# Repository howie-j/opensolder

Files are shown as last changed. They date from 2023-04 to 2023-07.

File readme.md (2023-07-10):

# OpenSolder
Fully open source JBC T245-compatible soldering station and tool holder  
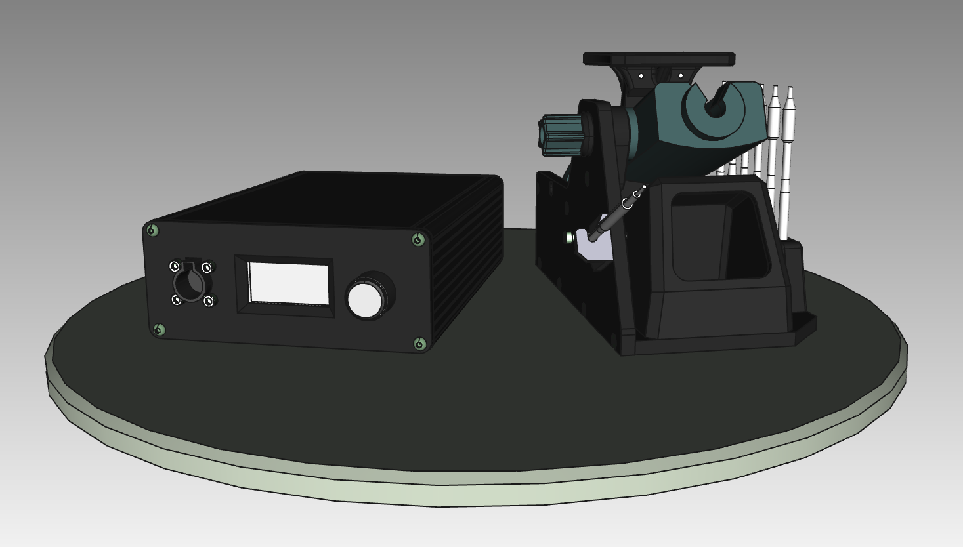
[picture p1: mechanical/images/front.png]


## Introduction
When my cheap T12 clone soldering station went up in smoke, I started looking into either buying a JBC CDB, or building a proper soldering station. The internet is already crowded with DIY JBC compatible stations, but most are poorly documented, or does not have the quality-of-life features that the original have.

The [unisolder project](https://github.com/sparkybg/UniSolder-5.2) is very impressive, but way to complex and "universal" for my needs. [Marco Reps](https://youtu.be/GYIiOkr6x9o) built a cool C470 station that i liked the simplicity of, and this project is highly inspired by that.

## Goals:
- _T12 clone_ form factor that does not take up valuable bench space
- JBC T245 tip compatibility, with similar performance to the original station
- QoL features that the CDB station have, like auto standby, tip remover, holder, tip cleaner etc.
- Simple design using cheap off-the-shelf parts
- A compact handpiece stand with these features:
	- Detection when the handpiece is in the tool holder (auto standby)
	- Detection when you're about to swap tips (cut power)
	- Integrated tip remover, tip storage, tip cleaner and a soldering wire spool holder
	- Simple to build

## Design Specifications
- 24V toroidal transformer
- Zero Crossing AC switching
- OLED display and rotary encoder for adjusting temperature
- Compact and low profile design
- Super fast heatup time (~4s)
- Hardware should be mostly 3D printable, and easy to build using regular tools

## Station
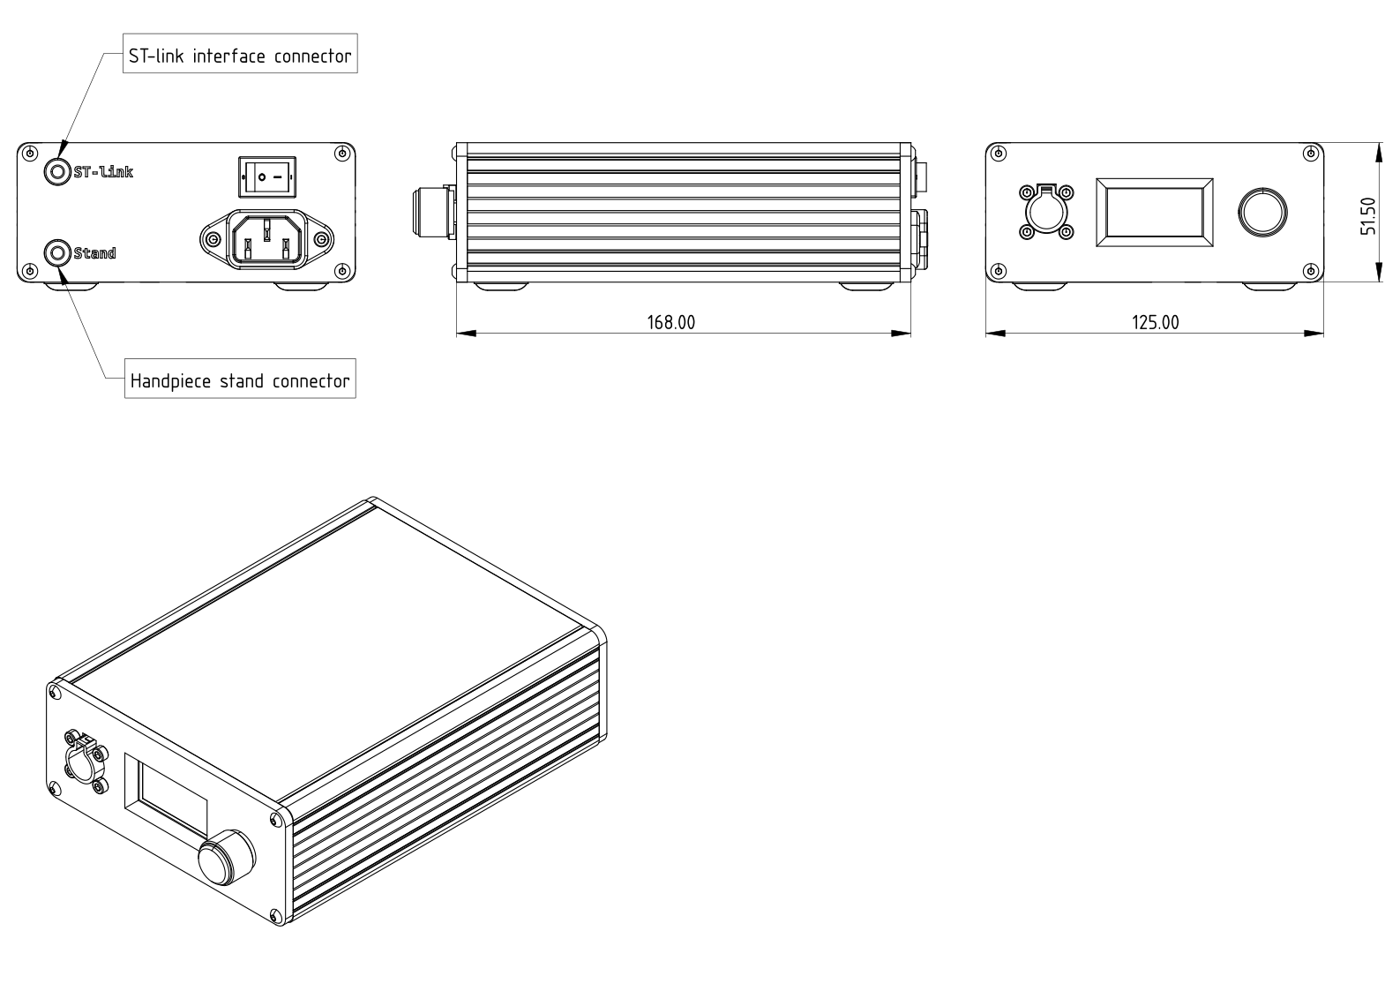
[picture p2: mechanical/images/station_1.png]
  
The station is built in a Hammond enclosure, with a center mounted transformer. The PCB is mounted to the custom front panel, and all 230VAC connections is in the rear of the chassis.
There is two connectors on the rear panel, one for connecting to the stand, and an optional ST-link connector for firmware upgrades.

## Stand
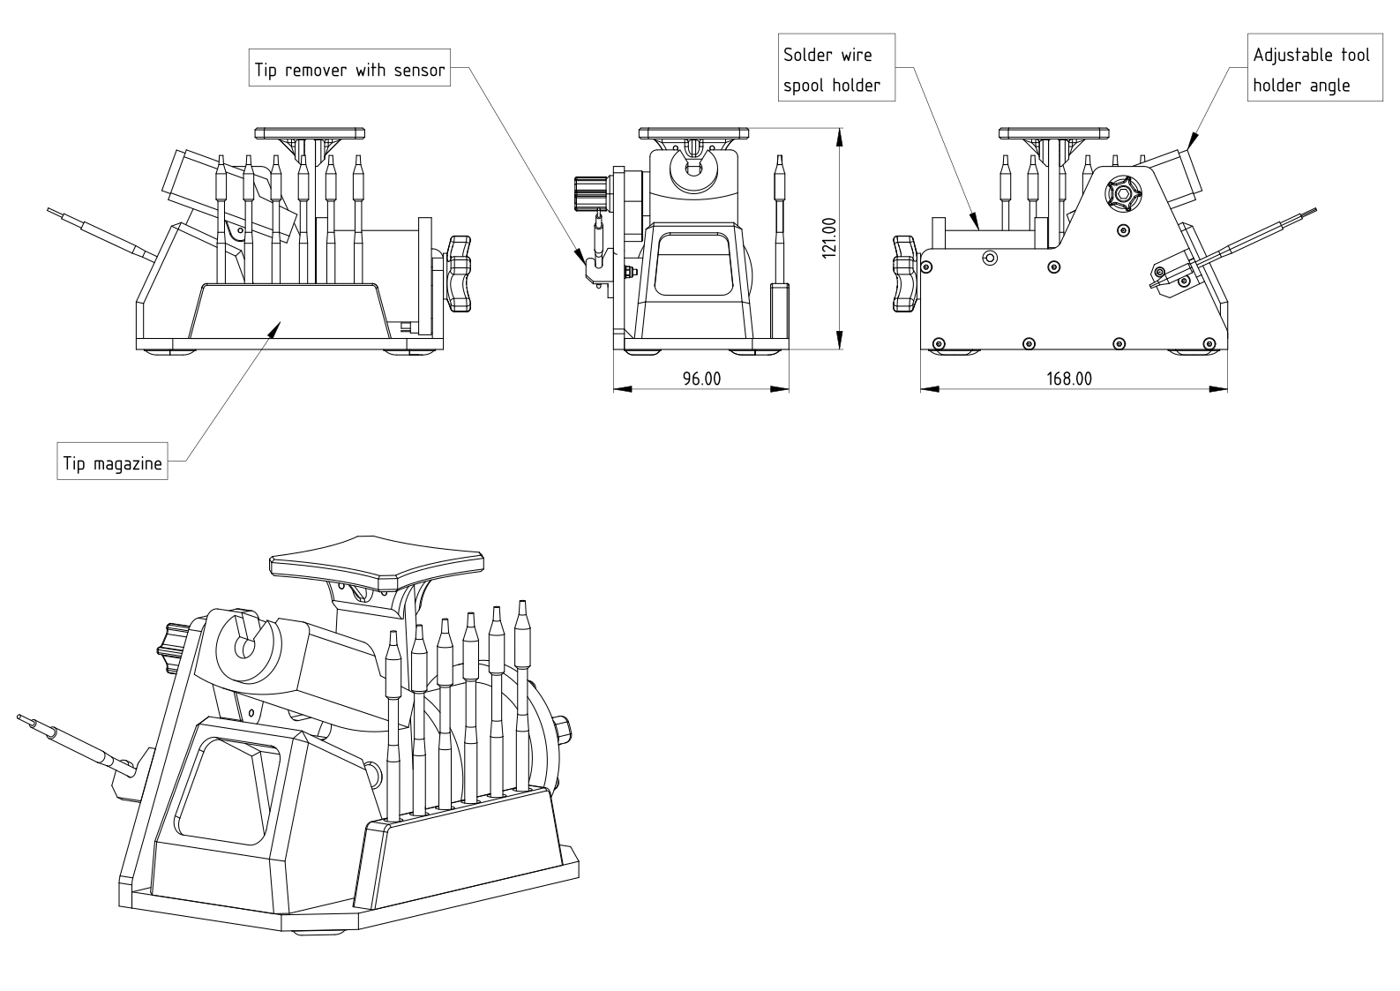
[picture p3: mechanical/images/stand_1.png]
  
The stand is made of 3D-printed parts, a genuine JBC tool holder, a tip remover made from aluminium angle and some fasteners. Most parts can be made from aluminium sheet if that is preferred.

## Schematic
This is the internal connections of the JBC C245 cartridge:  
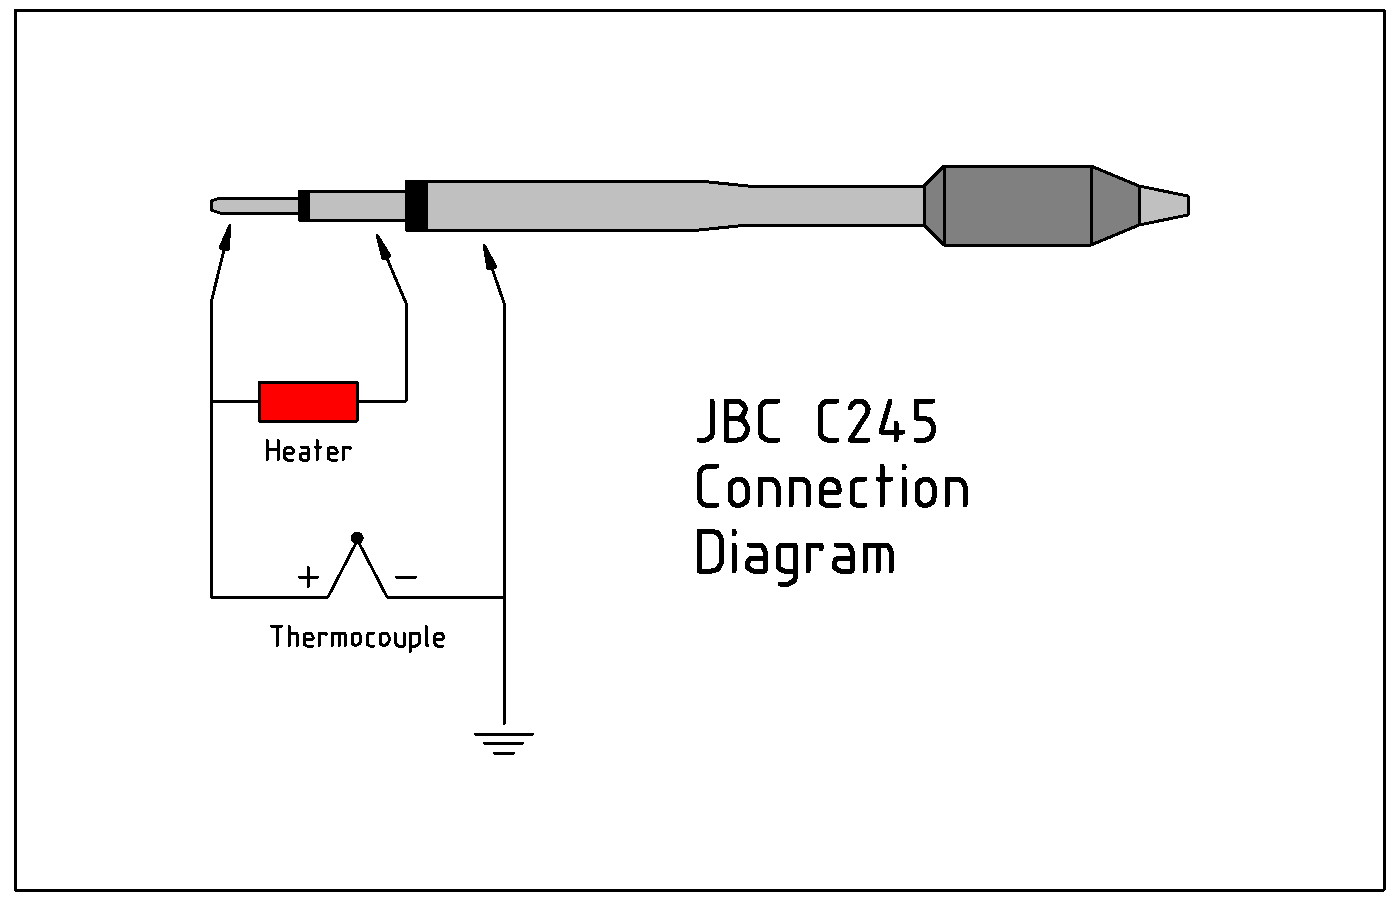
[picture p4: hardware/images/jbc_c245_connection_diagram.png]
  

[__The schematic__](https://github.com/howie-j/OpenSolder/raw/main/hardware/schematic.pdf) is divided into three sheets: AC, Analog and MCU.

### AC
The 24VAC input is fused, then connected directly to the tip center pin (5). Switching is done with two N-channel mosfets, driven by a Si8751 isolated gate driver.

Zero cross detection is done with an AC optocoupler, and the current is limited by three 10k resistors (to reduce BOM items). This solution triggers the ZeroCross about 90uS prematurely, and that is compensated for in firmware.

The MCU and thermocouple frontend must be electrically isolated, and a 24V to 5V DCDC PSU module solves that problem. The DCDC-supply is preregulated with a 24V linear regulator, and post-regulated to 3.3V with a LDO. This power supply chain is in need of some simplification, but the components are few and cheap, and it works great for now.

### Analog
The thermocouple signal is amplified with a MAX4238 chopper opamp, with a fairly arbitrary amplification of 221, since temperature calibration is done in firmware anyway. No negative supply rail means the thermocouple can't sense lower temperatures than room temp, but that's not needed for a soldering station.

Long handpiece wires means lots of crosstalk, so a pair of diodes clamps the thermocouple input at Vf. The MCU pin _TIP_CLAMP_ is driven low when power is applied to the handpiece, to clamp noise on the opamp input. When its time to measure tip temperature, the pin is set to input, and a delay waits for the RC filter to stabilize.

To sense if there is a tip cartridge in the handpiece, _TIP_CHECK_ is driven high. The low impedance of the thermocouple + heater (a few Ω's) will create a very low voltage drop. If the tip is removed, the Vf of the input protection diode will drive _THERMOCOUPLE_ADC_ close to 3.3V.

### MCU
A STM32F072 is used since I have a few of them in stock, but almost any STM32 could be adapted to work. To sense PCB temperature (and for cold junction compensation), an I2C temp sensor is added. The MCU might have an internal temperature sensor, but  have not looked into that yet.

The rotary encoder and handpiece stand inputs are filtered using plain RC filters. This, combined with the input hysteresis, removes most input noise. The TIM encoder inputs also have additional filtering and FSM redundancy.

## PCB
[___Check out this interactive BOM___](http://htmlpreview.github.io/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)

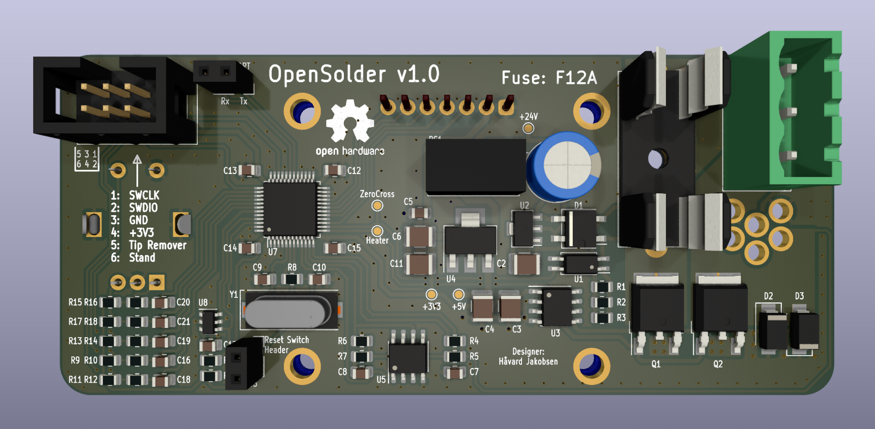
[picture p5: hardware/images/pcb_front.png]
  
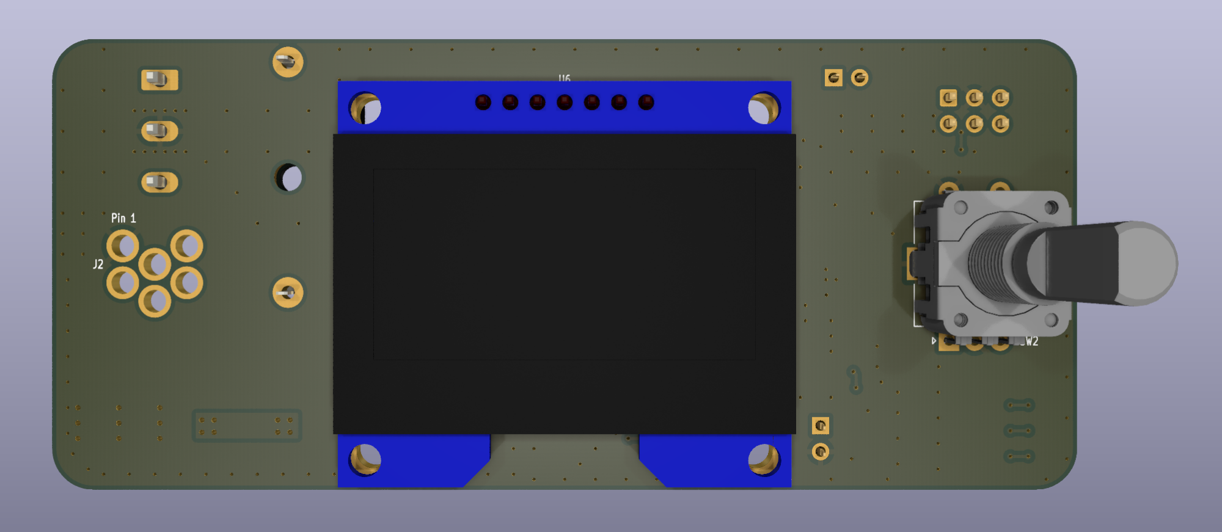
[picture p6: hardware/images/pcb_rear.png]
  
The PCB is quite low density, uses 0805 SMD components and is fully hand solderable with a microscope. Connections to the rear connectors (stand and ST-link) is done via a 6-pin IDC connector, so no crimping of tiny connector pins are necessary. The PCB is mounted to the front panel via the rotary encoder and the handpiece connector.

## Firmware
The firmware is simple and functional, and uses a modified hysteresis temperature controller that is very fast but has some initial overshoot. Currently all default values are set in _opensolder.h_, and are reset when the station is powered off.

### TODO
Nothing is currently missing for regular functionality. However some features would be cool to have:

- More accurate temp control (PID or other controller)
- User changeable default values
- Menu for changing default values
- Better looking UI

## Links and Sources
[The unisolder project](https://github.com/sparkybg/UniSolder-5.2)  
[Marco Reps](https://youtu.be/GYIiOkr6x9o)  
[foldvarid93's JBC Soldering Station](https://github.com/foldvarid93/JBC_SolderingStation)  
[johnmx's eevblog thread](https://eevblog.com/forum/testgear/jbc-soldering-station-cd-2bc-complete-schematic-analysis/)

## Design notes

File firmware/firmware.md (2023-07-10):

### Installation
Install STM32CubeIDE, click "Open project from filesystem" and select the "opensolder" folder.

### Code structure
All cube-generated files are untouched, except for calling opensolder_init() and opensolder_main() in main.c.
- opensolder.c is the "main" file, containing the init calls, superloop and state machine
- opensolder.h contains most constants for easy editing
- temperature.c handles interrupts, does temperature control, adc reading, tip check and such
- gui.c contains all functions to draw graphics to the OLED display

There is a fair bit of comments in the code, and better documentation can be provided if requested. If you have a question or see an issue, just open an issue in this repo.

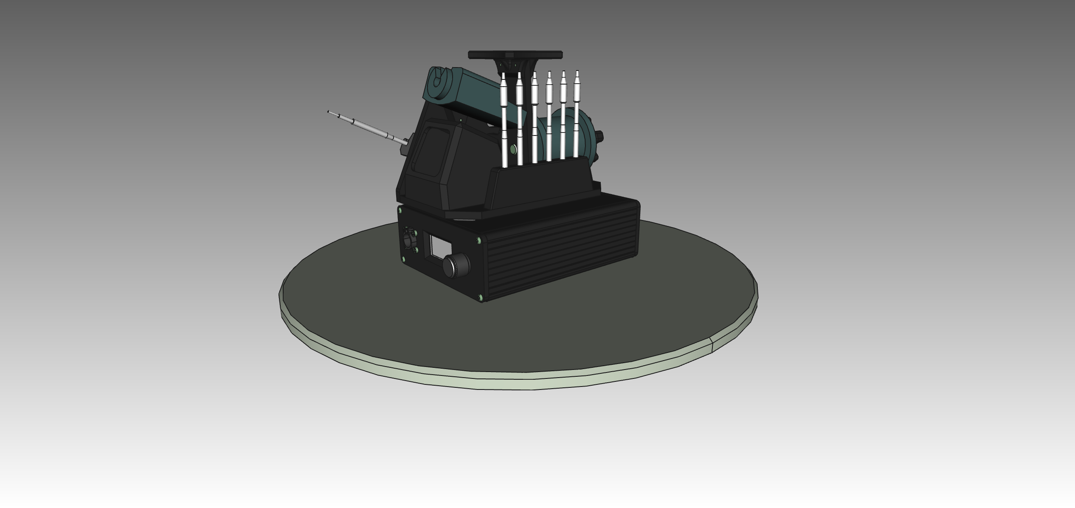
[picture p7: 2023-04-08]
mechanical/images/top_1.png

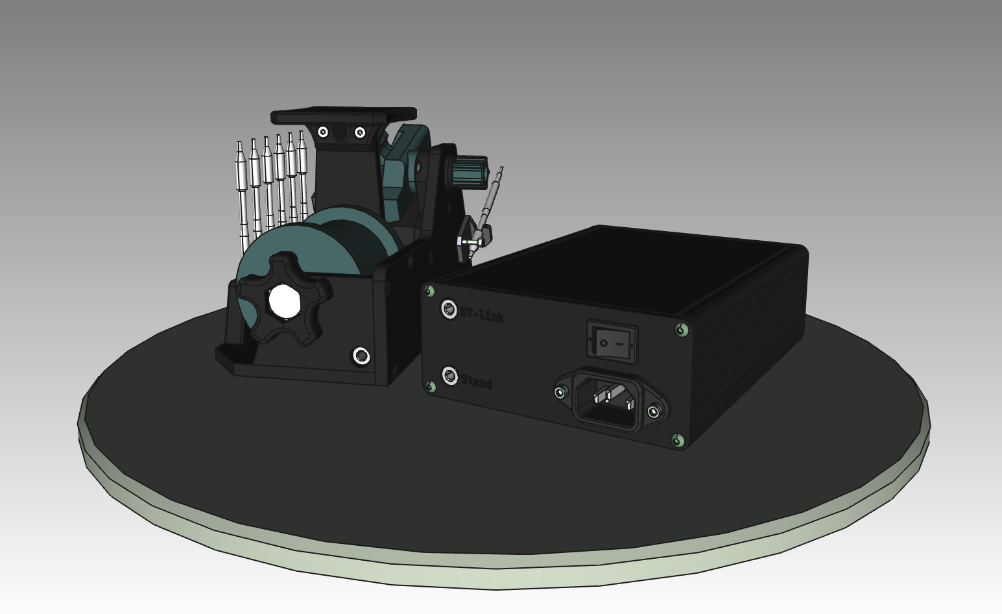
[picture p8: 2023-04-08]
mechanical/images/rear.png

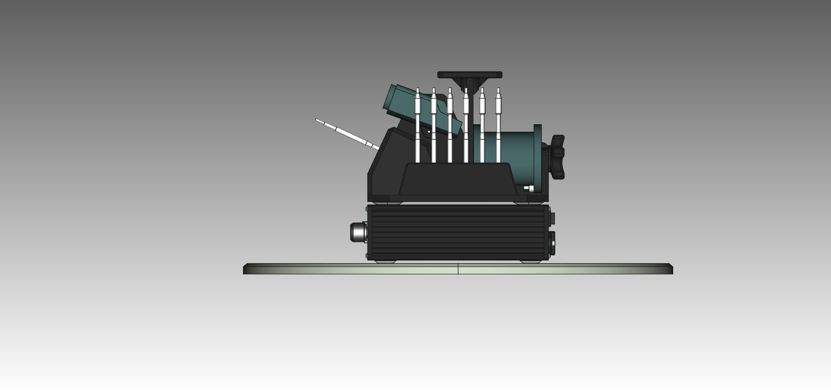
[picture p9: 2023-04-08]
mechanical/images/top_6_ortho.png

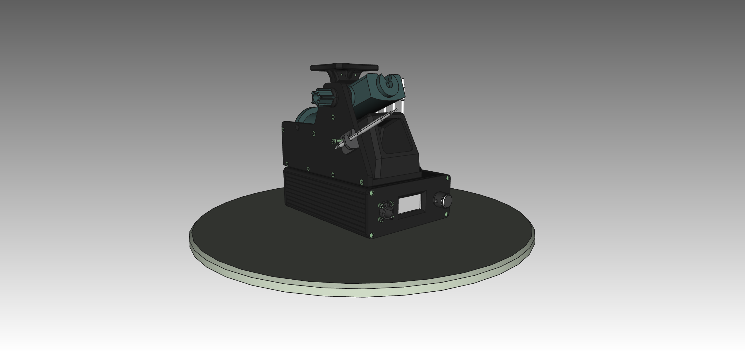
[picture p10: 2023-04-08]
mechanical/images/top_2.png

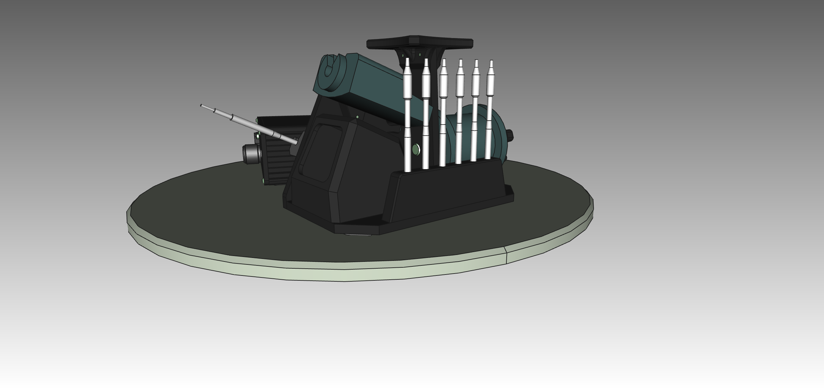
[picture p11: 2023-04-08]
mechanical/images/side_2.png

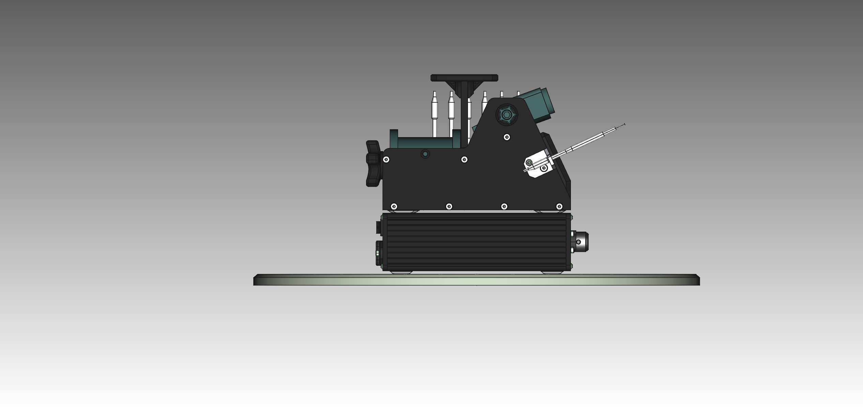
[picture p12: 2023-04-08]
mechanical/images/top_4_ortho.png

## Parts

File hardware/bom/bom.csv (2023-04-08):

Item | Qty | Reference(s) | Value | LibPart | Footprint | Datasheet
1 | 1 | C1 | 47u | Device:C_Polarized_Small | Capacitor_THT:CP_Radial_D8.0mm_P3.50mm | ~
2 | 5 | C2, C3, C4, C6, C11 | 1u | Device:C_Small | Capacitor_SMD:C_1210_3225Metric | ~
3 | 10 | C5, C8, C12, C13, C14, C15, C16, C17, C18, C19 | 100n | Device:C_Small | Capacitor_SMD:C_0805_2012Metric | ~
4 | 3 | C7, C20, C21 | 10n | Device:C_Small | Capacitor_SMD:C_0805_2012Metric | ~
5 | 2 | C9, C10 | 20p | Device:C_Small | Capacitor_SMD:C_0805_2012Metric | ~
6 | 1 | D1 | MB6S-TP | 0_Howie:MB6S-TP | Package_TO_SOT_SMD:TO-269AA
7 | 2 | D2, D3 | S1M | 0_Howie:S1M | Diode_SMD:D_SMA
8 | 1 | F1 | Fast 12A | Device:Fuse | Fuse:Fuseholder_Cylinder-5x20mm_Schurter_0031_8201_Horizontal_Open | ~
9 | 1 | J1 | AC_Input | Connector_Generic:Conn_01x03 | Connector_Phoenix_MSTB:PhoenixContact_MSTBVA_2,5_3-G_1x03_P5.00mm_Vertical | ~
10 | 1 | J2 | Hirose RPC1-12RB-6P(71) | 0_Howie:Hirose RPC1-12RB-6P(71) | 0_Howie:Hirose_RPC1
11 | 1 | J3 | SWD | Connector_Generic:Conn_01x06 | Connector_IDC:IDC-Header_2x03_P2.54mm_Vertical | ~
12 | 1 | J4 | UART | Connector_Generic:Conn_01x02 | Connector_PinSocket_2.54mm:PinSocket_1x02_P2.54mm_Vertical | ~
13 | 1 | J5 | Reset_Switch | Connector_Generic:Conn_01x02 | Connector_PinSocket_2.54mm:PinSocket_1x02_P2.54mm_Vertical | ~
14 | 1 | PS1 | PDSE1-S24-S5-S | 0_Howie:PDSE1-S24-S5-S | 0_Howie:PDSE1_DCDC
15 | 2 | Q1, Q2 | KIA50N06BD | 0_Howie:KIA50N06BD | Package_TO_SOT_SMD:TO-252-2
16 | 10 | R1, R2, R3, R4, R5, R9, R11, R13, R15, R17 | 10k | Device:R_Small | Resistor_SMD:R_0805_2012Metric | ~
17 | 1 | R6 | 22k | Device:R_Small | Resistor_SMD:R_0805_2012Metric | ~
18 | 1 | R7 | 100 | Device:R_Small | Resistor_SMD:R_0805_2012Metric | ~
19 | 1 | R8 | 390 | Device:R_Small | Resistor_SMD:R_0805_2012Metric | ~
20 | 5 | R10, R12, R14, R16, R18 | 100k | Device:R_Small | Resistor_SMD:R_0805_2012Metric | ~
21 | 2 | R19, R20 | 3k3 | Device:R_Small | Resistor_SMD:R_0805_2012Metric | ~
22 | 1 | SW2 | PEC11R-4220F-S0024 | 0_Howie:PEC11R-RotEnc | 0_Howie:RotaryEncoder_PEC11R_PEC12R | ~
23 | 1 | TP1 | ZeroCross | 0_Howie:TestPoint_D1_Pad | TestPoint:TestPoint_Pad_D1.0mm | ~
24 | 1 | TP2 | +24V | 0_Howie:TestPoint_D1_Pad | TestPoint:TestPoint_Pad_D1.0mm | ~
25 | 1 | TP3 | Heater | 0_Howie:TestPoint_D1_Pad | TestPoint:TestPoint_Pad_D1.0mm | ~
26 | 1 | TP4 | +5V | 0_Howie:TestPoint_D1_Pad | TestPoint:TestPoint_Pad_D1.0mm | ~
27 | 1 | TP5 | +3V3 | 0_Howie:TestPoint_D1_Pad | TestPoint:TestPoint_Pad_D1.0mm | ~
28 | 1 | U1 | VOS628A | 0_Howie:VOS628A | Package_SO:SOP-4_4.4x2.6mm_P1.27mm
29 | 1 | U2 | L78L24_SOT89 | Regulator_Linear:L78L24_SOT89 | Package_TO_SOT_SMD:SOT-89-3 | http://www.st.com/content/ccc/resource/technical/document/datasheet/15/55/e5/aa/23/5b/43/fd/CD00000446.pdf/files/CD00000446.pdf/jcr:content/translations/en.CD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
30 | 1 | U3 | Si8751 | 0_Howie:Si8751 | Package_SO:SOIC-8_3.9x4.9mm_P1.27mm
31 | 1 | U4 | AP2111H-3.3 | 0_Howie:AP2111H-3.3 | Package_TO_SOT_SMD:SOT-223
32 | 1 | U5 | MAX4238ASA | Amplifier_Operational:MAX4238ASA | Package_SO:SOIC-8_3.9x4.9mm_P1.27mm | http://datasheets.maximintegrated.com/en/ds/MAX4238-MAX4239.pdf
33 | 1 | U6 | OLED | 0_Howie:OLED_SSD1306_SPI_1.54 | 0_Howie:OLED_SSD1306_SPI_1.54
34 | 1 | U7 | STM32F072CBTx | MCU_ST_STM32F0:STM32F072CBTx | Package_QFP:LQFP-48_7x7mm_P0.5mm | http://www.st.com/st-web-ui/static/active/en/resource/technical/document/datasheet/DM00090510.pdf
35 | 1 | U8 | PCT2075GV | 0_Howie:PCT2075GV | Package_SO:TSOP-6_1.65x3.05mm_P0.95mm | https://www.nxp.com/docs/en/data-sheet/PCT2075.pdf
36 | 1 | Y1 | Crystal_8MHz | 0_Howie:Crystal_8MHz | Crystal:Crystal_SMD_HC49-SD | ~

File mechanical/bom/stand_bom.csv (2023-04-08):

Position | Component | Part Number / Specification | Manufacturer | Material | Qty | Description
1 | Base Panel | OpenSolder Stand Base Panel | DIY | ABS | 1 | Alternative material: Aluminium sheet
2 | Side Panel | OpenSolder Stand Side Panel | DIY | ABS | 1 | Alternative material: Aluminium sheet
3 | Rear Panel | OpenSolder Stand Rear Panel | DIY | ABS | 1 | Alternative material: Aluminium sheet
4 | Mid Panel | OpenSolder Stand Mid Panel | DIY | ABS | 1 | Alternative material: Aluminium sheet
5 | Handle | OpenSolder Stand Handle | DIY | ABS | 1
6 | Tool Holder SCD | 12994 | JBC | - | 1
7 | Tool Holder Adapter | OpenSolder Tool Holder Adapter | DIY | ABS | 1
8 | Tool Holder Washer | OpenSolder Tool Holder Washer | DIY | ABS | 1
9 | Spool Knob | OpenSolder Spool Knob | DIY | ABS | 1
10 | Tip Magazine | OpenSolder Tip Magazine | DIY | ABS | 1
11 | Tip Cleaner | OpenSolder Tip Cleaner | DIY | ABS | 1
12 | Tip Remover Bracket | OpenSolder Tip Remover Bracket | DIY | Aluminium | 1
13 | Connector | MJ-064H | Marushin Electric | - | 1
14 | Rubber Pads | Self adhesive | - | - | 4
15 | CS Flat Head Screw M3X8 | ISO 10642 | - | - | 3
16 | CS Flat Head Screw M3X16 | ISO 10642 | - | - | 15
17 | Socket Head Cap Screw M3x25 | ISO 4762 | - | - | 1
18 | Washer M3 | ISO 7089 | - | - | 1
19 | Locknut M3 | ISO 10511 | - | - | 1
20 | Hexagon Screw M10x80 | ISO 4014 | - | - | 1

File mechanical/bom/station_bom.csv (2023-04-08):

Position | Component | Part Number / Specification | Manufacturer | Material | Qty | Description
1 | Enclosure | 1455Q1602BK | Hammond | - | 1
2 | PCBA | OpenSolder PCBA | DIY | - | 1
3 | Front Panel | OpenSolder Front Panel | DIY | ABS | 1 | Alternative material: Aluminium sheet
4 | Rear Panel | OpenSolder Front Panel | DIY | ABS | 1 | Alternative material: Aluminium sheet
5 | Transformer Spacer | OpenSolder Transformer Spacer | DIY | ABS | 1
6 | Transformer kit | TI-044229-ME-ES | Noratel | - | 1 | 24VAC, 100VA min, D105xH46 max size
7 | IDC Power Inlet | 703W-00/04 | Qualtek | - | 1
8 | Power Switch | CWSB11AA2F | NKK Switches | - | 1
9 | Fuse holder inline | 01500274ZXU | Littelfuse Inc. | - | 1
10 | Connector | MJ-064H | Marushin Electric | - | 2
11 | Rubber Pads | Self adhesive | - | - | 4
12 | Knob | Ø6, D-shaft, set screw | - | - | 1
13 | Socket Head Cap Screw M3x8 | ISO 4762 | - | - | 4
14 | Socket Head Cap Screw M3x12 | ISO 4762 | - | - | 2
15 | CS Flat Head Screw M3X12 | ISO 10642 | - | - | 1
16 | Washer M3 | ISO 7089 | - | - | 3
17 | Locknut M3 | ISO 10511 | - | - | 3
18 | Button Head Screw M3.5x16 | ISO 7380 | - | - | 8
19 | CS Flat Head Screw M5x20 | ISO 10642 | - | - | 2
20 | Locknut M5 | ISO 10511 | - | - | 2

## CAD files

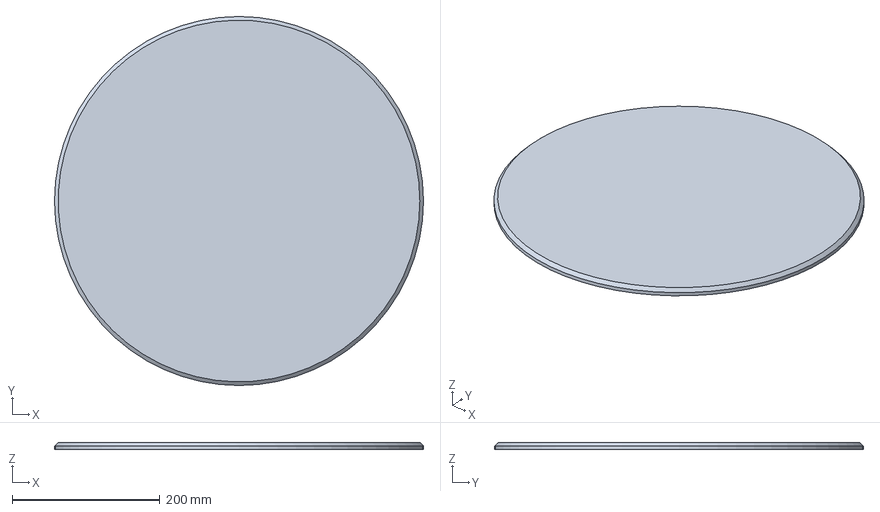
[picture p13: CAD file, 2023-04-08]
mechanical/freecad/Render Assembly.FCStd
500.0 x 500.0 x 10.0 mm

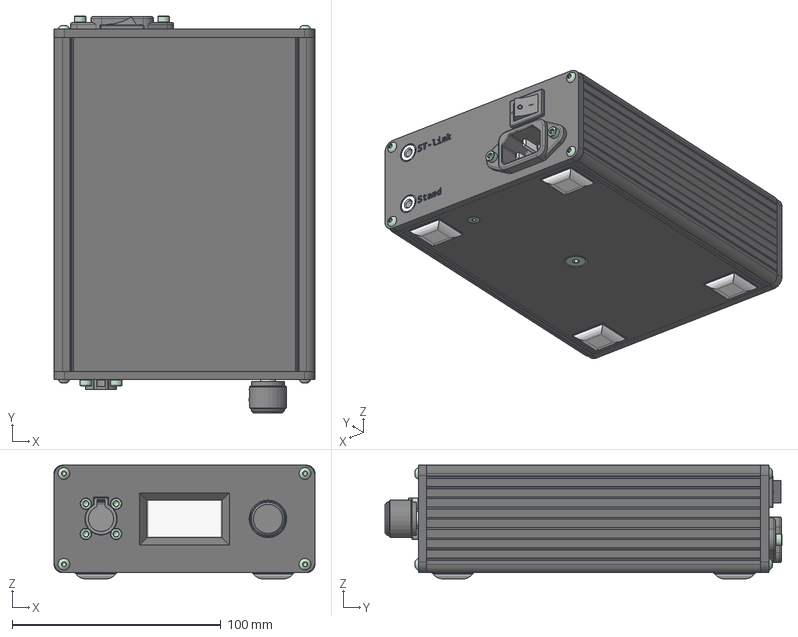
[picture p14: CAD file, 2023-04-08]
mechanical/step/station_step_files/station_assembly.step
125.0 x 190.2 x 54.5 mm
Enclosure_1455Q1602BK_Extrusion
Enclosure_1455Q1602BK_Cap
Transformer_Spacer
Foam x 2
Transformer
Transformer_Washer
Front_Panel
Rear_Panel
openSolderV0.2 PCB
PEC11R
Connector_Minijack_MJ-064H x 2
SS7BVDERB
SS7B-001-63
SS7B-002-63
SS7B-002-064
_CWSB-body
_CWSB2-nonillumin_rocker
_CWSB1F-nonillumin_trmnls
Fuse_Holder_01500274ZXU
Rotary_Encoder_Knob
Rubber_Pad x 4
M5x20-Screw
M5x20-Screw001
M5-Nut
M5-Nut001
M3x16-Screw
M3x16-Screw043
M3x16-Screw044
M3x16-Screw045
M3x16-Screw046
M3x16-Screw047
M3x16-Screw048
M3x16-Screw049
M3x12-Screw
M3x12-Screw089
M3-Washer
M3-Washer083
M3-Nut
M3-Nut085
M3x8-Screw
M3x8-Screw145
M3x8-Screw146
M3x8-Screw147
M3x12-Screw090
M3-Washer084
M3-Nut086

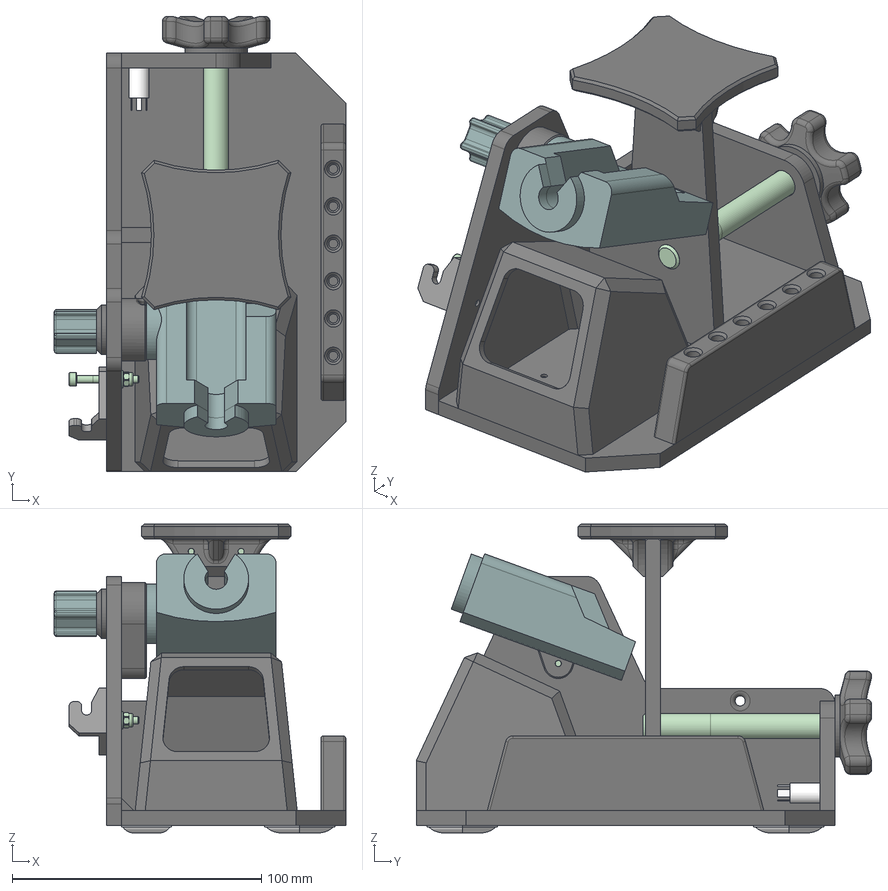
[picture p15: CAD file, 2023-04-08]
mechanical/step/stand_step_files/stand_assembly.step
117.0 x 182.8 x 124.0 mm
Base_Panel
Side_Panel
Rear_Panel
Mid_Panel
Handle
Tool_Holder
Tool_Holder_Adapter
Tool_Holder_Washer
Tool_Holder_Screw
Tip_Cleaner
Tip_Remover_Bracket
Tip_Magazine
Spool_Knob
Connector_Minijack_MJ-064H
Rubber_Pad x 4
M10x80-Screw
M3x16-Screw620 x 15
M3x8-Screw087 x 3
M3x25-Screw
M3-Washer
M3-Nut

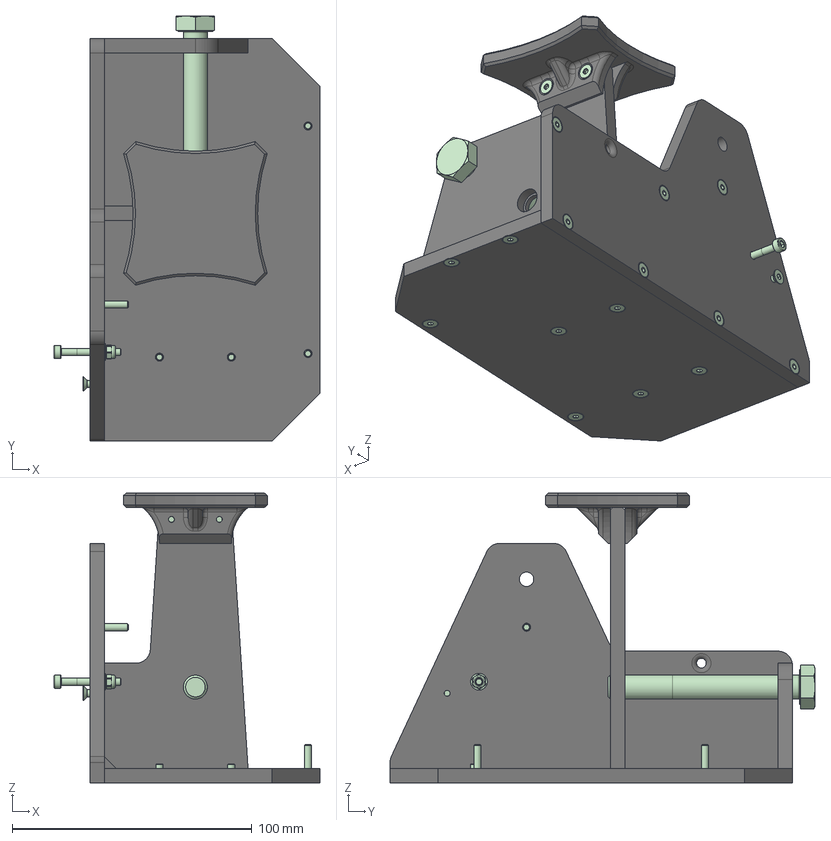
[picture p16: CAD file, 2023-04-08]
mechanical/freecad/OpenSolder Stand.FCStd
111.0 x 177.4 x 121.0 mm
Base_Panel x 2
Side_Panel x 2
Rear_Panel x 2
Mid_Panel x 2
Handle x 2
M10x80-Screw x 3
M3x16-Screw620 x 3
M3x16-Screw621 x 3
M3x16-Screw622 x 3
M3x16-Screw623 x 3
M3x16-Screw624 x 3
M3x16-Screw625 x 3
M3x16-Screw626 x 3
M3x16-Screw627 x 3
M3x16-Screw628 x 3
M3x16-Screw x 3
M3x16-Screw629 x 3
M3x16-Screw630 x 3
M3x16-Screw631 x 3
M3x16-Screw632 x 3
M3x16-Screw633 x 3
M3x8-Screw087 x 3
M3x8-Screw088 x 3
M3x8-Screw x 3
M3x25-Screw x 3
M3-Washer x 3
M3-Nut x 3

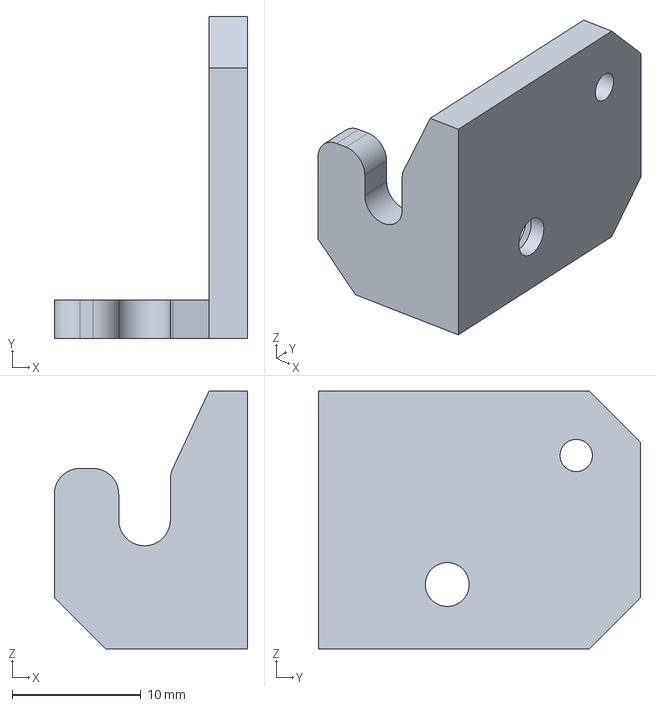
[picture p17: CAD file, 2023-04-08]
mechanical/freecad/Parts/Tip Remover Bracket.FCStd
15.0 x 25.0 x 20.0 mm

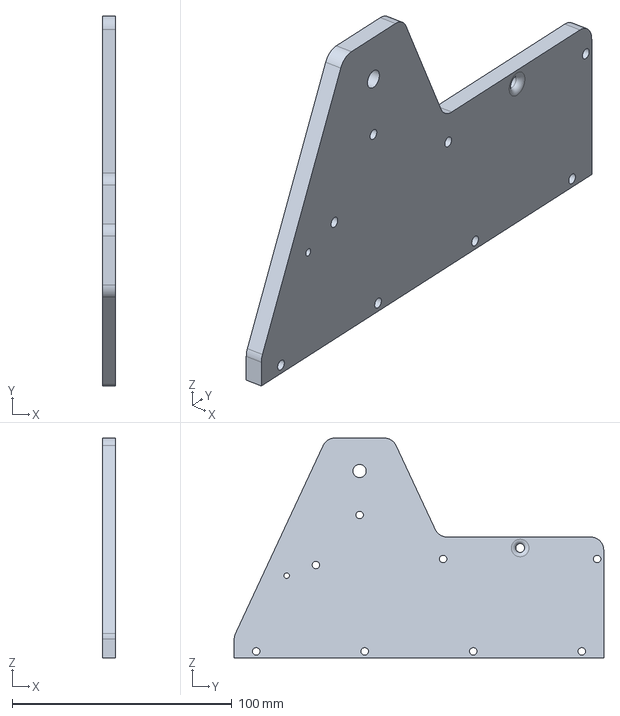
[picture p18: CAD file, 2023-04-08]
mechanical/step/stand_step_files/side_panel.step
6.00 x 168.0 x 100.0 mm

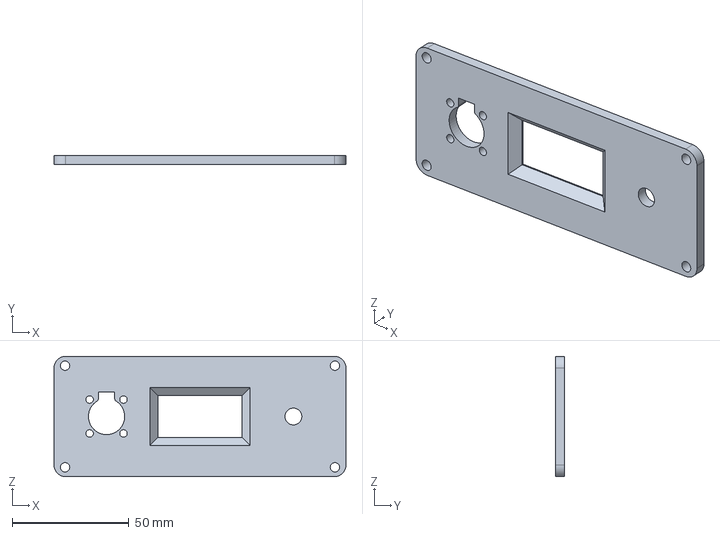
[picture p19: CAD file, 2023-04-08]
mechanical/step/station_step_files/station_front_panel.step
125.0 x 4.00 x 51.5 mm

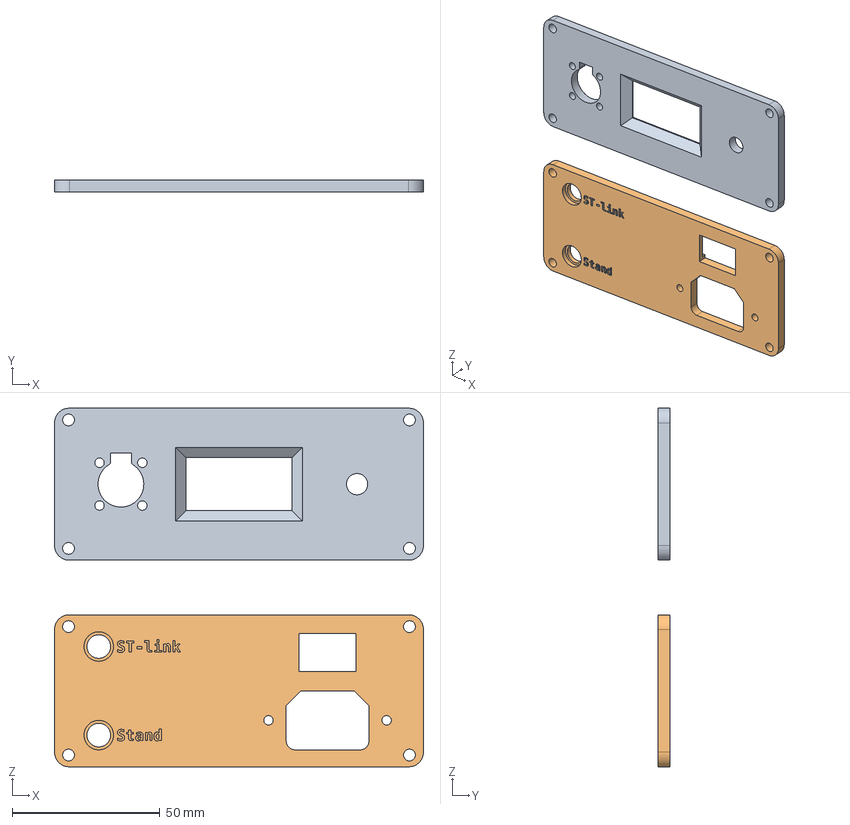
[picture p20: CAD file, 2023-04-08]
mechanical/freecad/Parts/Panels.FCStd
125.0 x 4.00 x 121.5 mm
Front_Panel
Rear_Panel

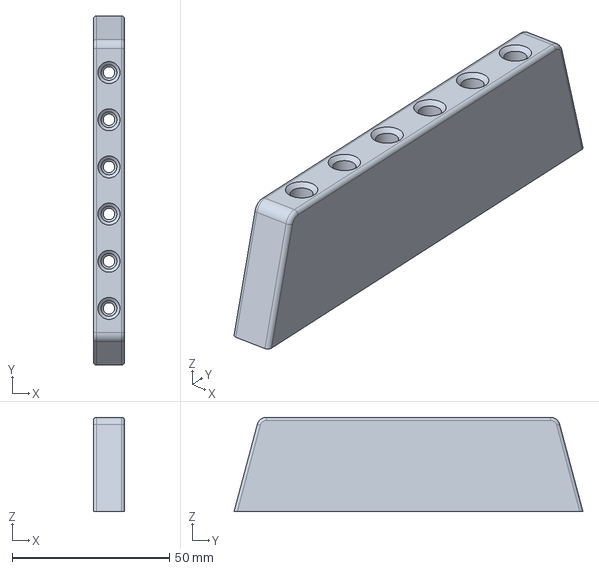
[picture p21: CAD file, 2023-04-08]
mechanical/step/stand_step_files/tip_magazine.step
10.0 x 111.0 x 30.0 mm

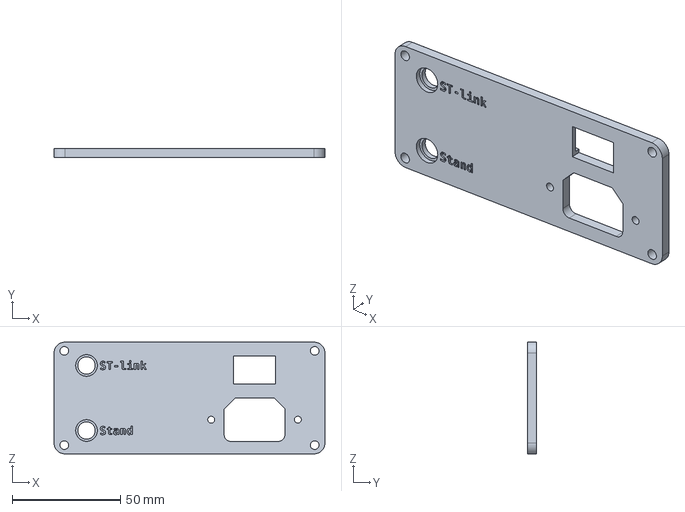
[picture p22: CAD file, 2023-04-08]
mechanical/step/station_step_files/station_rear_panel.step
125.0 x 4.00 x 51.5 mm

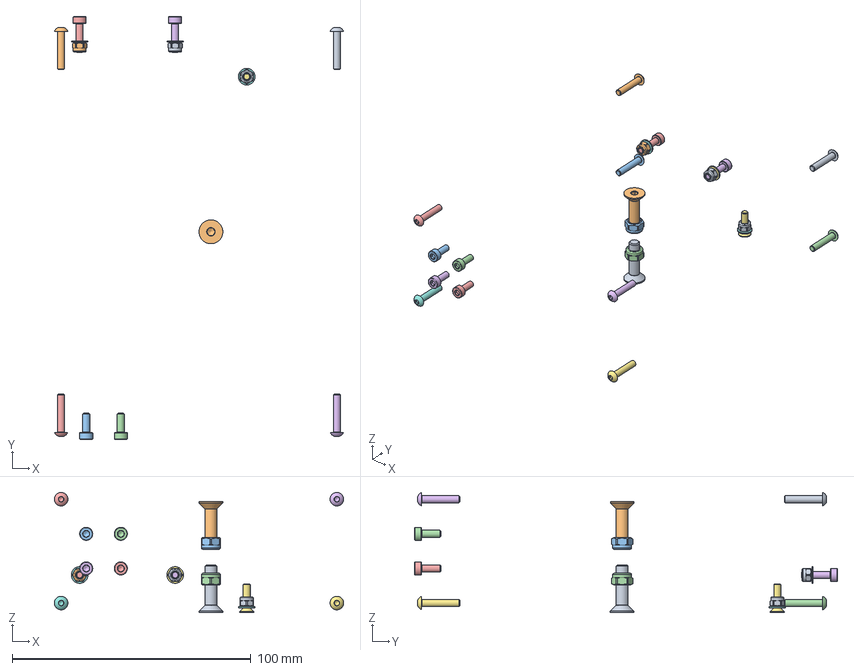
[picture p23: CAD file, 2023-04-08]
mechanical/freecad/OpenSolder Station.FCStd
121.2 x 177.2 x 50.4 mm
M5x20-Screw x 3
M5x20-Screw001 x 3
M5-Nut x 3
M5-Nut001 x 3
M3x16-Screw x 3
M3x16-Screw043 x 3
M3x16-Screw044 x 3
M3x16-Screw045 x 3
M3x16-Screw046 x 3
M3x16-Screw047 x 3
M3x16-Screw048 x 3
M3x16-Screw049 x 3
M3x12-Screw x 3
M3x12-Screw089 x 3
M3-Washer x 3
M3-Washer083 x 3
M3-Nut x 3
M3-Nut085 x 3
M3x8-Screw x 3
M3x8-Screw145 x 3
M3x8-Screw146 x 3
M3x8-Screw147 x 3
M3x12-Screw090 x 3
M3-Washer084 x 3
M3-Nut086 x 3

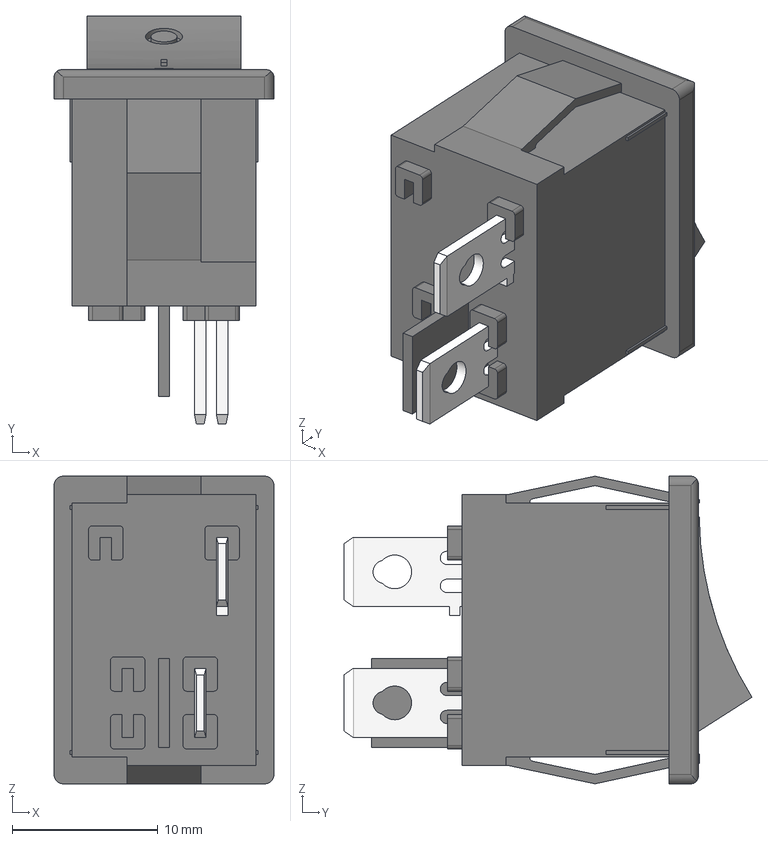
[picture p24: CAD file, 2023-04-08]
mechanical/freecad/Parts/Rocker Switch CWSB11AA2F.FCStd
15.1 x 28.0 x 21.1 mm
_CWSB-body
_CWSB2-nonillumin_rocker
_CWSB1F-nonillumin_trmnls

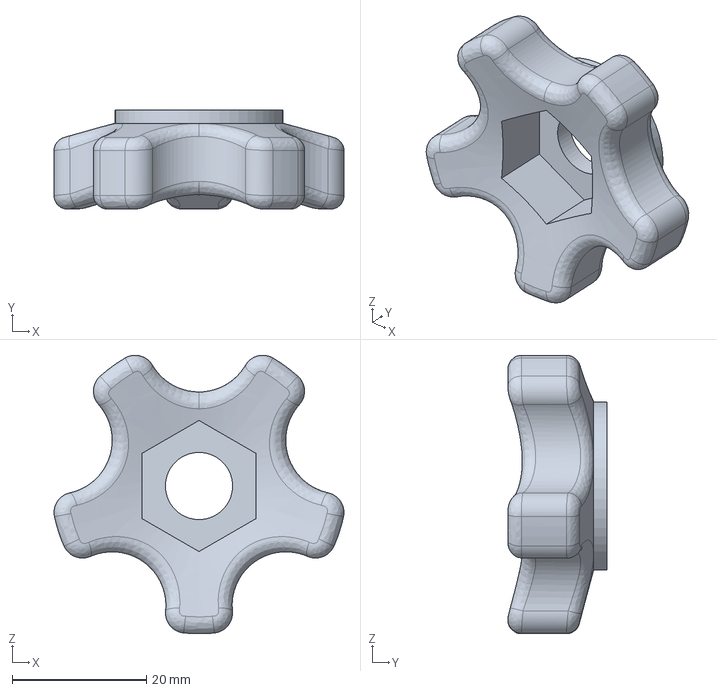
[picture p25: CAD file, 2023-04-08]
mechanical/step/stand_step_files/spool_knob.step
43.2 x 14.8 x 41.4 mm

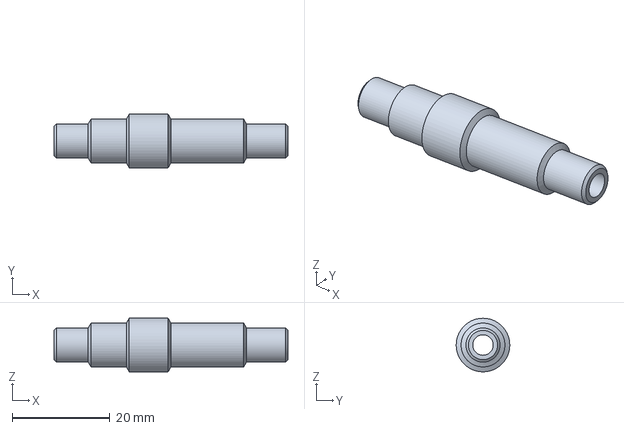
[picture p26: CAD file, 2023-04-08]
mechanical/freecad/Parts/Fuse Holder Inline.FCStd
48.0 x 11.0 x 11.0 mm

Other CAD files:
mechanical/step/stand_step_files/tool_holder_adapter.step
mechanical/freecad/Parts/Rotary Encoder Knob.FCStd
mechanical/step/stand_step_files/handle.step
mechanical/freecad/Parts/Tool Holder.FCStd
mechanical/freecad/Parts/Connector IEC-C14 703W-0004.FCStd
mechanical/freecad/Parts/Connector Minijack MJ-064H.FCStd
mechanical/freecad/Parts/Enclosure 1455Q1602BK.FCStd
mechanical/freecad/Parts/PCB.FCStd
mechanical/freecad/Parts/Rubber Pad.FCStd
mechanical/freecad/Parts/Spool Dummy.FCStd
mechanical/freecad/Parts/Spool Knob.FCStd
mechanical/freecad/Parts/Tip Cleaner.FCStd
mechanical/freecad/Parts/Tip Dummy.FCStd
mechanical/freecad/Parts/Tip Magazine.FCStd
mechanical/freecad/Parts/Tool Holder Adapter.FCStd
mechanical/freecad/Parts/Tool Holder Screw.FCStd
mechanical/freecad/Parts/Tool Holder Washer.FCStd
mechanical/freecad/Parts/Transformer Spacer.FCStd
mechanical/freecad/Parts/Transformer.FCStd
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

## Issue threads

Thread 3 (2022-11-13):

replacement for AP2111H-3.3

Knarf2807, 2022-11-13:
The AP2111H-3.3 is actually sold out in all distributors I looked for. I think I can replace it with a LD1117V33 or LM1117 (3V3). The dropout voltage is higher but it works with USB on an Arduino.

howie-j, 2022-11-13:
Yeah any LDO should work as long as Vin - Vout - Vdrop > 0V.

Closed 2023-01-23.

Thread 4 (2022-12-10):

[Build Thread] Soldering finished

Knarf2807, 2022-12-10:
Next steps:
Checking the voltages
Waiting for OLED
Flashing the software

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

howie-j, 2022-12-11:
Cool! I'll get working on publishing the firmware then!

howie-j, 2022-12-11:
Did you have any issues sourcing components, ordering the PCB or during assembly/soldering?

Knarf2807, 2022-12-12:
> Did you have any issues sourcing components, ordering the PCB or during assembly/soldering?

The order at jlcpcb with your gerber files was without any issue. Perfect! Thank you for your work.
I had to replace the LDO (AP2111H-3.3 -> LM1117 3.3 (AliExpress-Version)). It is pin-comaptible and works fine with other 5V-Sources.
And the fuse holder was not in stock (digikey). I replaced it with it's THR-pendant Schurter 3-132-873. Without a problem.

The rest of the BOM was a mix from Digikey and LCSC. Why a mix? The STM32 was only available at LCSC but not the Hirose Connector. But I didn't want a long search for a STM32-Replacement. For R6, C9 and C10 I took 0603-SMDs because I had it "in stock".

It's easy to solder with some SMD-experiences. Only the Hirose Connector was a little bit to narrow on the 24VAC-Connector as I came with my big 1,6mm chisel. But that was my fault.

Thank you for that good job. I like the Hardware.

Btw: You can see the "temp-overjumping" at an Ersa-Iron too. With a brand new Ersa you can see it in this video (time 9:25...): https://www.youtube.com/watch?v=CfsMkEtcwEI

Frank

howie-j, 2022-12-19:
Sorry for the slow reply, a bit busy at the moment. The mix of parts from Distrelec, Digikey and LCSC is mostly because i used whatever i had in stock. If there were any significant interrest in the project i could do a revision and simplify the BOM, perhaps only using JLCPCB stock parts etc. However github is full of soldering station project so thats probably not going to happen :)

I should probably make a PCB assembly instruction, as you probably found out you should solder the Hirose connector before the 24VAC terminal block, to get better access to the pins.

I managed to work on the firmware this weekend, and made some progress. I probably wont have time to finish a "beta" version until christmas/new years, however i could give you a link with the previous working version if you wish!

Knarf2807, 2022-12-20:
Hello! Oh... No problem. I'm very bussy to. Just Today the Display arrived, the cardridges are still on the way to me (it's my first JBC-Station) and i have to put the whole stuff in the case. I have time. :-)
When I'll be ready I send you a message.

For the assembly instruction: If you solder the Hirose-connector first, it's hard to solder the AC terminal block. The worst Hirose-Pin is the middle. It is not collected. So my favorite for the instruction would be: "To solder the middle pin is not necessary.". But at the end it was my dump fault.

Yes, github is full of stations. But I think there are many I don't like. Your station has a good schematic. And it looks very beautiful. That's why I hope it will work. :-)
I ordered a stand from china. When it will arrive I give you a feedback if it is a good choice.

Knarf2807, 2023-01-24:
First impression: looks fine and does it's job. I have to finish the case.

Thank you very much for your work. I will test it in the next weeks and give you more feedback.

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

Knarf2807, 2023-02-08:
!!! FINISHED !!! And I love it!

Now you can see, why it took so long. I "redesigned" the enclosure, mainly to have the hirose-connector on the back.

So I put the PCB on the back. For that I have to use a cable directly (not a plug) and the switch moved aproximatly 1 cm outside. Not my favorite design, but in practice it doesn't matter because you don't see it and you can feel it good.
On the front now I only need the display and the encoder. The 230V fuse is now in the enclosure (a cable-fuse-holder).

But why?
1. I like the clean front
2. I found this China-stand. It is cheaper than the original JBC-Tip-holder from the bom and is an out of the box stand.

I modified the stand, so that it communicates with the station. I changed the very simple PCB inside. Now the "Handpiece in stand"- and "tip-change"-event works with the china-stand. The cable-holder is an original from JBC. For communication between stand and station I use pin 3 and 4 from the Hirose-connector.

I didn't find a nice connector for the programming interface. So I put a cable inside and have to screw off the front.

That's all, I think. Now the pictures:

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

Thanks a lot again for your work. :-)

Frank

howie-j, 2023-02-09:
Congratulations, thats really cool!

I was also contemplating placing the tool connector on the rear of the unit, but decided against it to simplify the build. I might look into doing that on a v2 someday!

Knarf2807, 2023-02-09:
Than I am your man. 😁

I didn't think it completly over, but I think the best way for that are two PCBs. One POWER-PCB on the back and one controller-board in the front. But with less cables as possible...

In my enclosure it is very tide between transformer and PCB. Not the best solution for 230V.

Thank you very much for your feedback.

howie-j, 2023-07-10:
Closing this issue, but feel free to give an update if you find any bugs or annoyances that should be adressed 👍

BBroadbent, 2024-06-15:
Hi @Knarf2807 would you mind sharing the link (or product name) to the soldering stand you've used - looks great

howie-j, 2024-06-18:
Hi @BBroadbent, i would guess Knarf used the AIXUN T3A Stand, you can find it on aliexpress.

Closed 2023-07-10.

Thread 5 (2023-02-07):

[ISSUE] Freece after Tool Change Detection

Knarf2807, 2023-02-07:
If the MCU detects the Tool change, the station freeces. The temperature in the display does not drop. The "energy bar" freece and I can't change the target temperatur.

It takes some seconds until unfreece.

At the "handpeace in stand" - event it works fine.

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

howie-j, 2023-02-07:
Yes that's correct. I did not think of this as an issue, as i never leave the tool/handpiece in the tip change bracket/sensor, i only use it to instantly remove the tip. And when the tip is removed the display changes from default display to display_message until a tip is inserted. The delay is there to be able to insert a new tip by hand and not burn your fingers🤕 The delay can also be modified in the opensolder.h file.

If you have a recommendation on how to improve the gui and program flow, please share! And if you want to play around yourself, the [TIP_CHANGE_STATE in opensolder.c line 85 and downwards.](https://github.com/howie-j/OpenSolder/blob/main/firmware/opensolder/Core/Src/opensolder.c)

Knarf2807, 2023-02-08:
That's a good advice. And I think you are right. In practice it's a feature, not a bug.

Perhaps (impovement with low prio) the frozen display can be changed. Similar to the "handpiece in stand"-event. I will try. Perhaps my programming-skills are good enough.

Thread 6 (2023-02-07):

[QUESTION] what does the push button?

Knarf2807, 2023-02-07:
For me the push button in the encoder has nö funktion. Is that right or is it a bug in my soldering work?

I can't find a fault with my Multimeter and your KiCad files.

And if it is right: Why is 400°C the highest target temperatur?

Thanks a lot for your answer and your work.

Frank

howie-j, 2023-02-07:
Hi, thanks a lot for testing and feedback!

The push button has no function as of now, however i plan to implement a simple menu for changing default values (default temp, standby temp etc), and then the push button will trigger that menu.

During development i used the push button as an on/off switch, so that i would not burn up my tips if i had any bugs in my code😅 So far no acccidents!

There is no reason for the 400'C max temp, other than that i never solder above 350-380'C. You can change most parameters such as temps, delays etc in this file before compiling: [](https://github.com/howie-j/OpenSolder/blob/main/firmware/opensolder/Core/Inc/opensolder.h)

I would recommend not setting the temp above 400-450'C, as that will shorten the tip life drastically. Also because of the quick temp drop reaction and abundant heating power, i find i can lower the temp probably 20-30'C below other stations i have used in the past.

- Håvard

Knarf2807, 2023-02-08:
Thank you very much for your fast answer. :-)

Than I be glad, that it is no solder-fault from me. At the beginning I expected a menu like you describe above.
The truth: I stressed the ENC-Footprint on the PCB "a little bit" because I desoldered it. The ENC No. 1 is allready not alive. I rebuild the front and the bag for me and hope I will finish today.

I come from a Ersa Pico and there I need sometimes the 450°C for desoldering or big planes, also with a 1,6mm chissel. But what I realized with the JBC T245: I need much less heat than with the Ersa Pico. That's why I believe 400°C would be enough for me. The cardridge-system is much better than the Ersa-heater.

Frank

Closed 2023-04-12.

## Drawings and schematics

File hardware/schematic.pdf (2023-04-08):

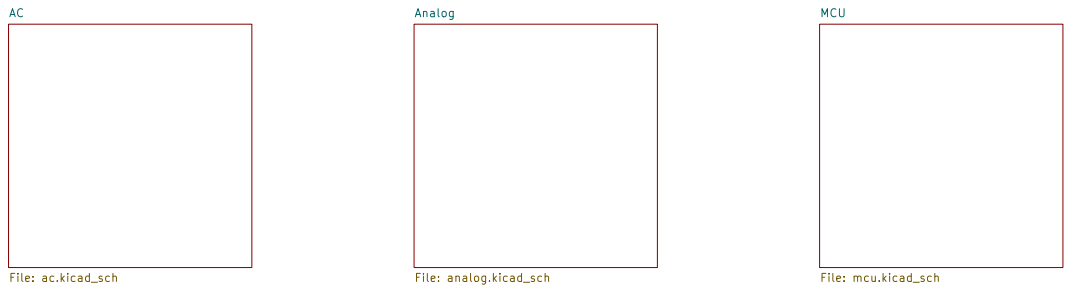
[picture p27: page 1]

OpenSolder - JBC T245 compatible soldering station

File: opensolder.kicad_sch Sheet: / Licence: GPL-3.0

Id: 1/4 Title: OpenSolder Station Schematic

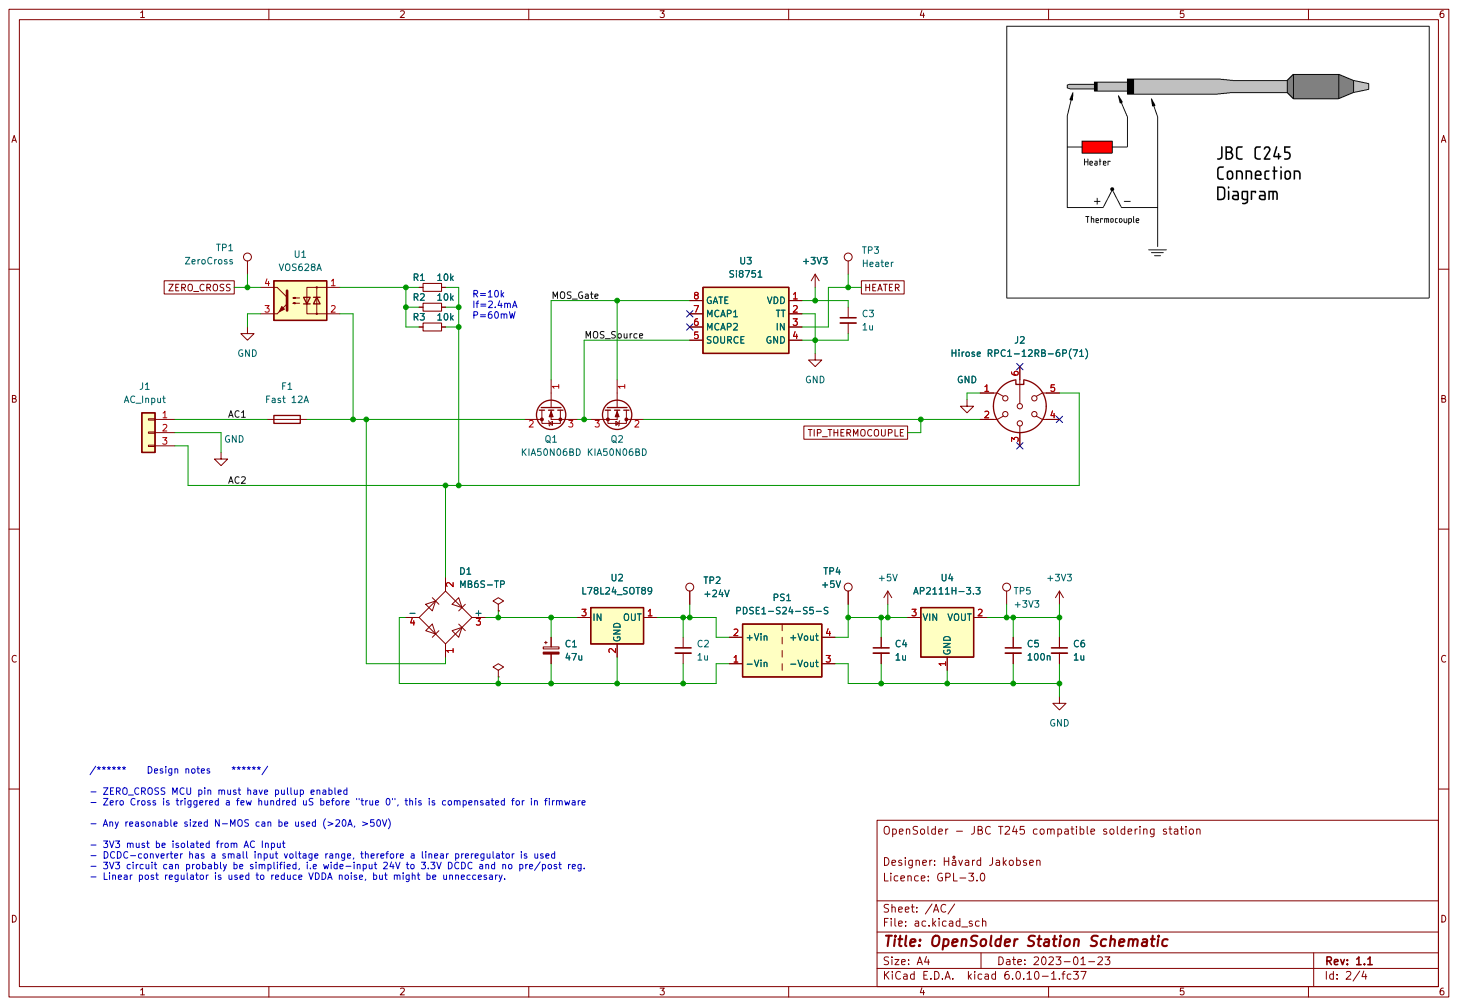
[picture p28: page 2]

- ZERO_CROSS MCU pin must have pullup enabled
- Zero Cross is triggered a few hundred uS before "true 0", this is compensated for in firmware

- Any reasonable sized N-MOS can be used (>20A, >50V)

OpenSolder - JBC T245 compatible soldering station

- 3V3 must be isolated from AC Input
- DCDC-converter has a small input voltage range, therefore a linear preregulator is used
- 3V3 circuit can probably be simplified, i.e wide-input 24V to 3.3V DCDC and no pre/post reg.
- Linear post regulator is used to reduce VDDA noise, but might be unneccesary.

File: ac.kicad_sch Sheet: /AC/ Licence: GPL-3.0

Id: 2/4 Title: OpenSolder Station Schematic

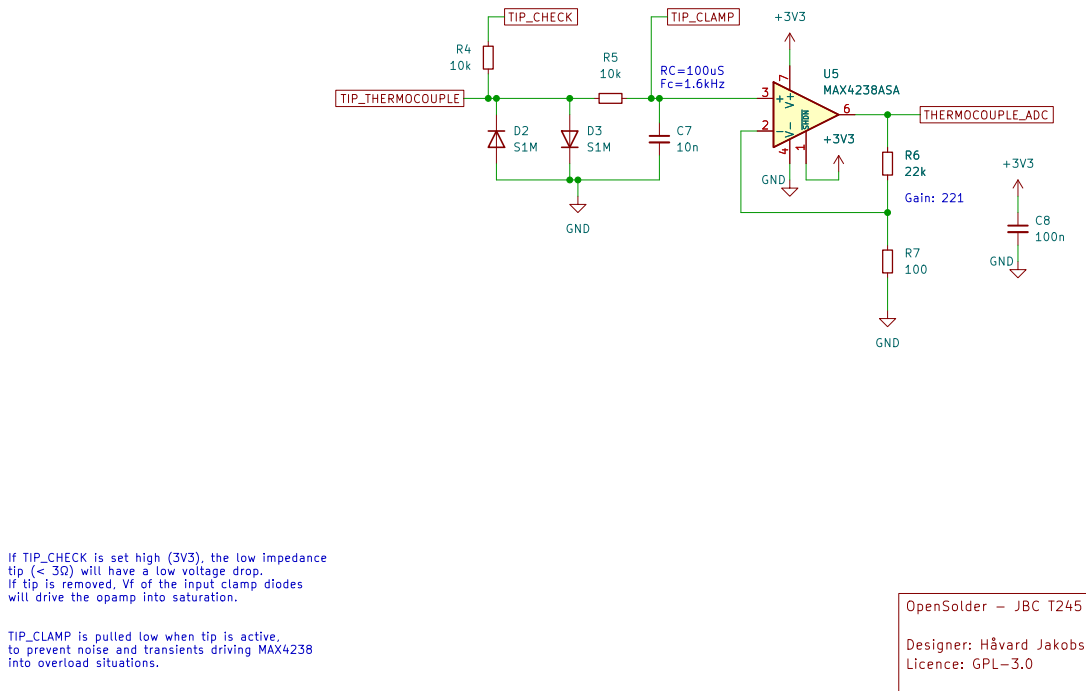
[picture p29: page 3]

OpenSolder - JBC T245 compatible soldering station C8

If TIP_CHECK is set high (3V3), the low impedance
If tip is removed, Vf of the input clamp diodes
will drive the opamp into saturation.

TIP_CLAMP is pulled low when tip is active,
to prevent noise and transients driving MAX4238
into overload situations.

Sheet: /Analog/ Licence: GPL-3.0

File: analog.kicad_sch
Id: 3/4 Title: OpenSolder Station Schematic

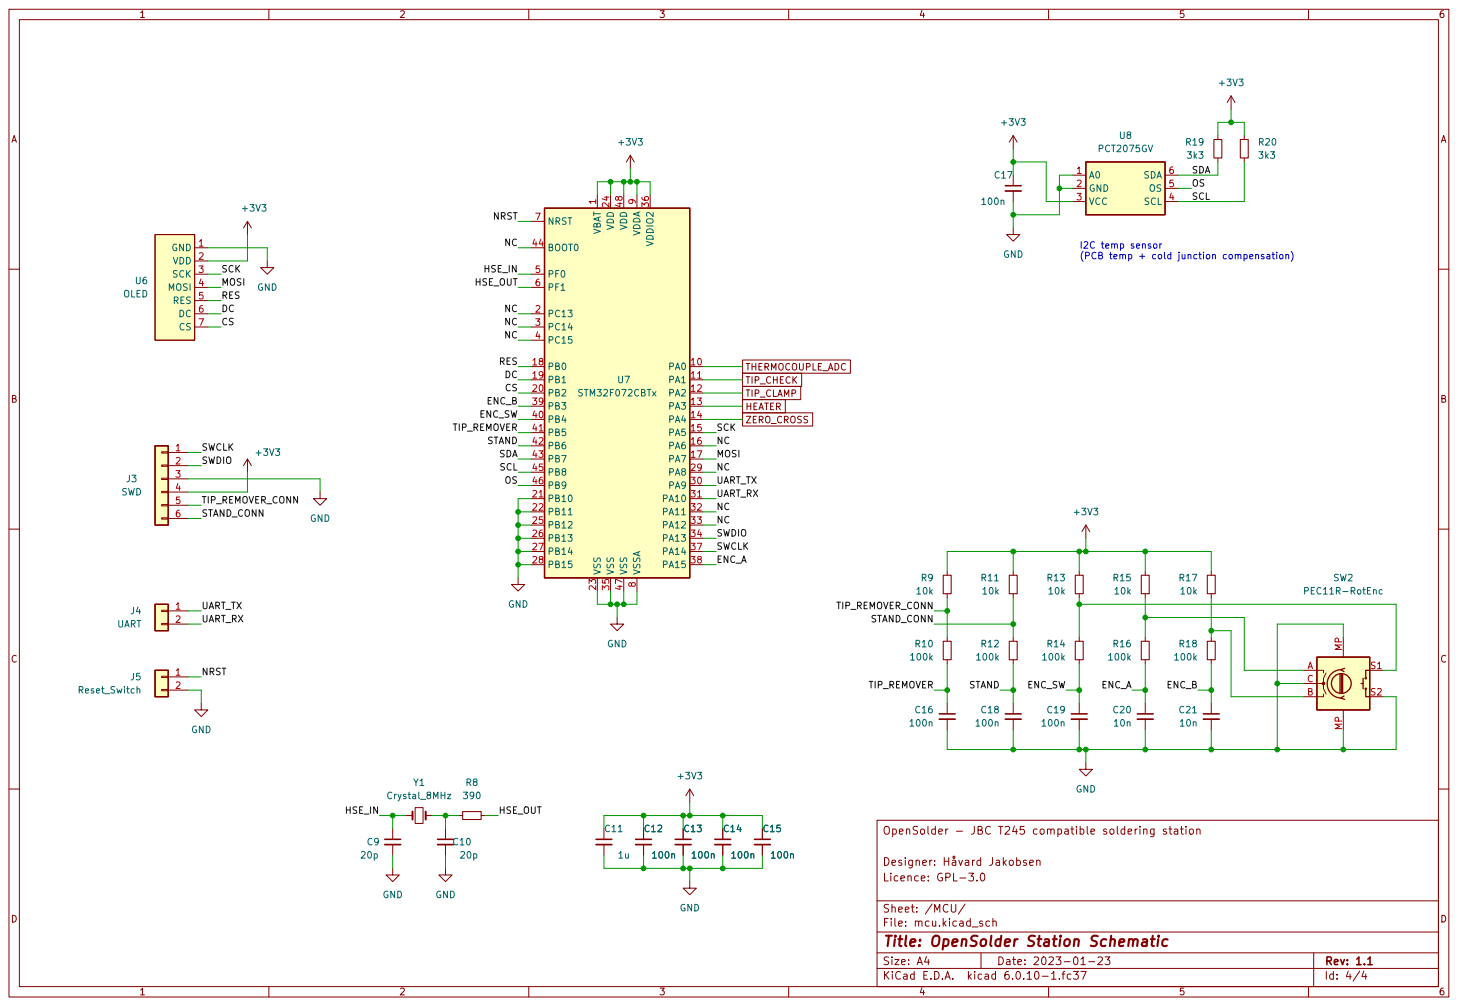
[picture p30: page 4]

1 PA0 10 PA1 11 PA2 12 PA3 13 PA4 14 PA5 15 PA6 16 PA7 17 PB0 18 PB1 19 PC13 2 PB2 20 PB10 21 PB11 22 VSS 23 VDD 24 PB12 25 PB13 26 PB14 27 PB15 28 PA8 29 PC14 3 PA9 30 PA10 31 PA11 32 PA12 33 PA13 34 VSS 35 VDDIO2 36 PA14 37 PA15 38 PB3 39 PC15 4 PB4 40 PB5 41 PB6 42 PB7 43 BOOT0 44 PB8 45 PB9 46 VSS 47 VDD 48 PF0 5 PF1 6 NRST 7 VSSA
CS HSE_OUT ENC_B RES HSE_IN

(PCB temp + cold junction compensation) C12

OpenSolder - JBC T245 compatible soldering station

File: mcu.kicad_sch Sheet: /MCU/ Licence: GPL-3.0

Id: 4/4 Title: OpenSolder Station Schematic

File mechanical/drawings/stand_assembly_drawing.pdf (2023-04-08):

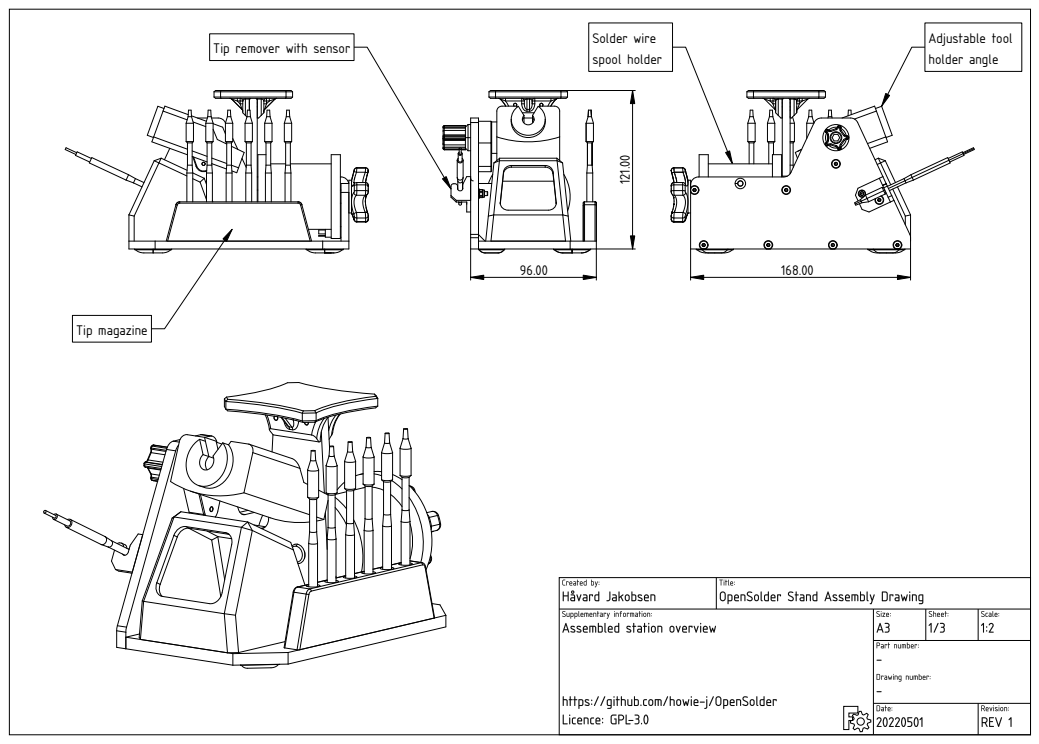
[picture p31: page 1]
Solder wire spool holder; Tip magazine; Adjustable tool holder angle

Tip remover with sensor

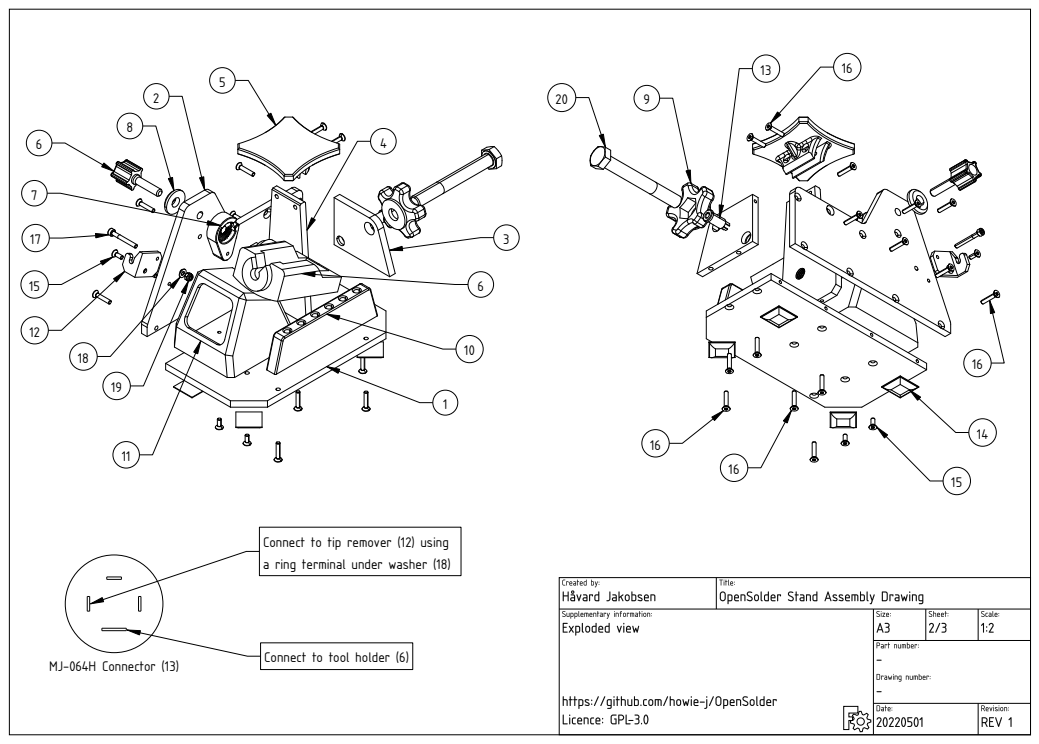
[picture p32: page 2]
MJ-064H Connector (13)

Connect to tip remover (12) using
a ring terminal under washer (18)

Connect to tool holder (6)

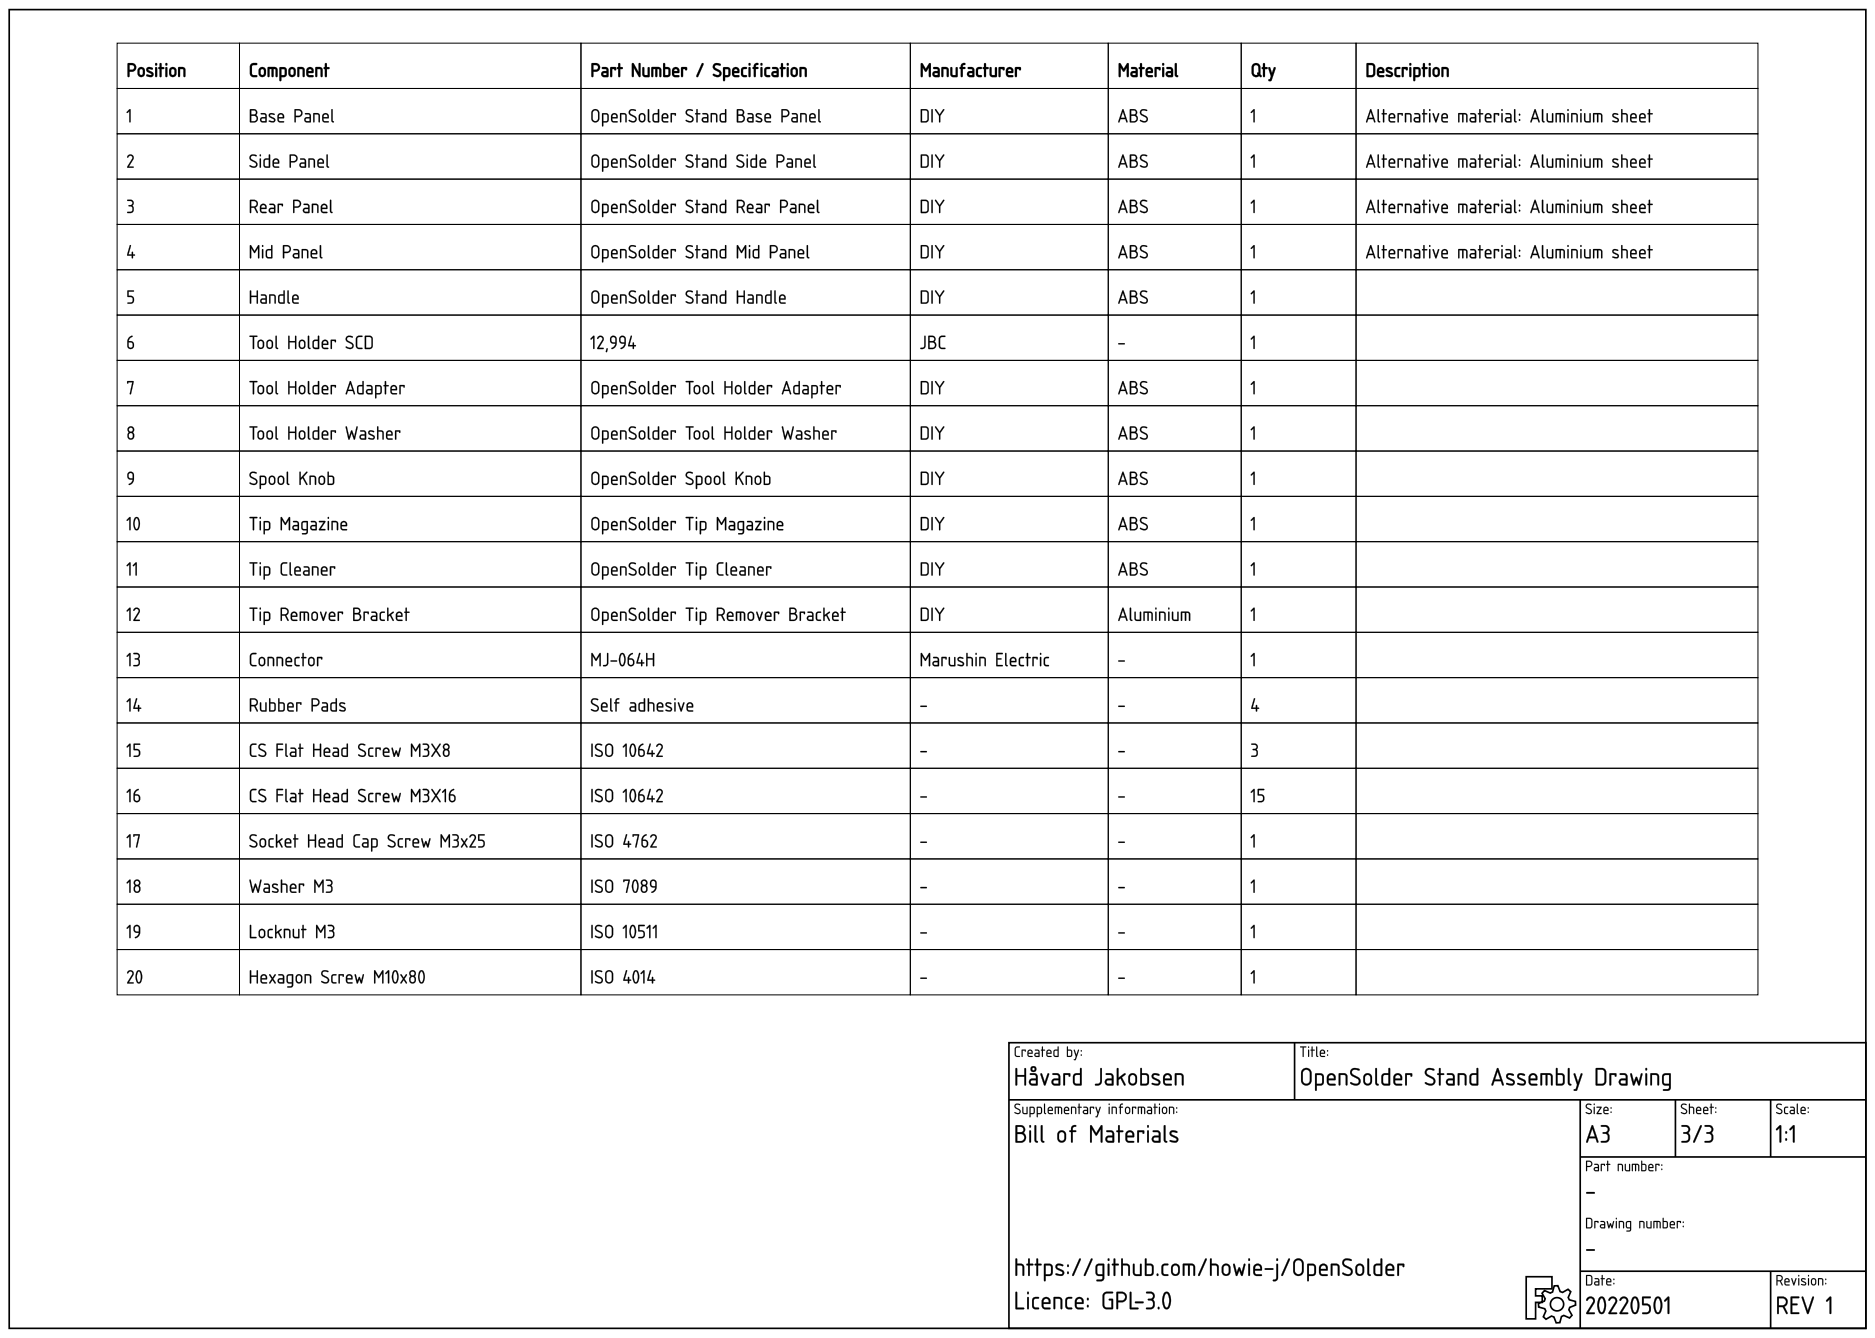
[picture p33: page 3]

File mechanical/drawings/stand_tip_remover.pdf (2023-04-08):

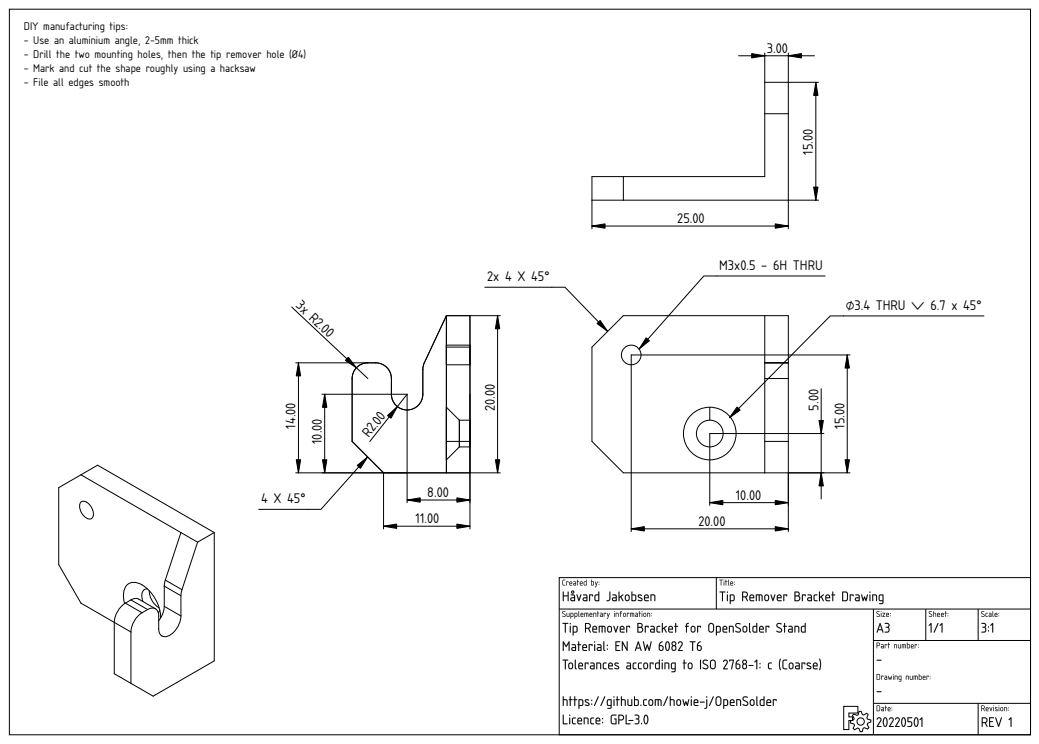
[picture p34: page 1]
⌀3.4 THRU ⌵ 6.7 x 45°; M3x0.5 - 6H THRU

DIY manufacturing tips:
- Use an aluminium angle, 2-5mm thick
- Drill the two mounting holes, then the tip remover hole (Ø4)
- Mark and cut the shape roughly using a hacksaw
- File all edges smooth

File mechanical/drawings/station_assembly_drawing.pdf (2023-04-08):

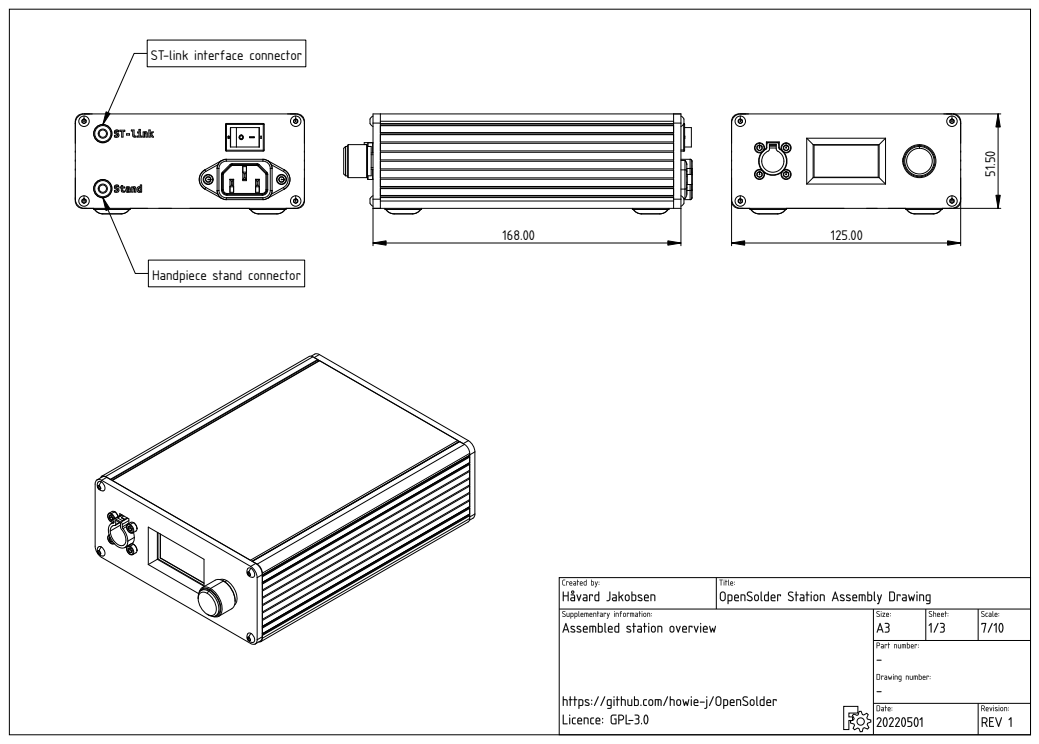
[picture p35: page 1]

ST-link interface connector

Handpiece stand connector

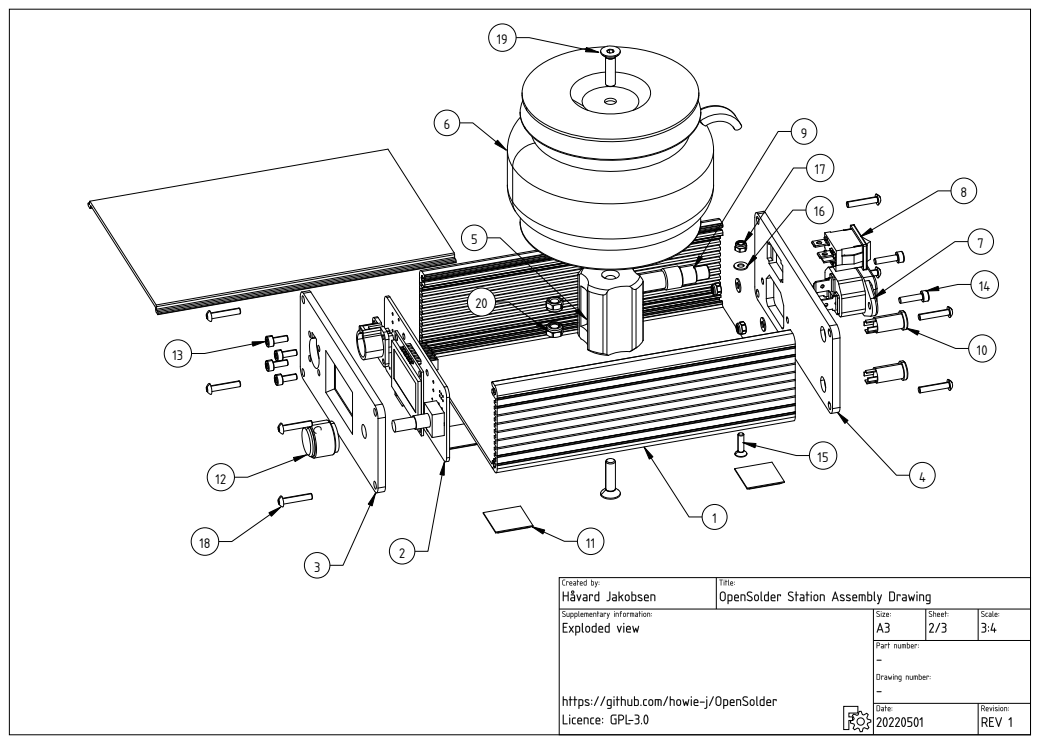
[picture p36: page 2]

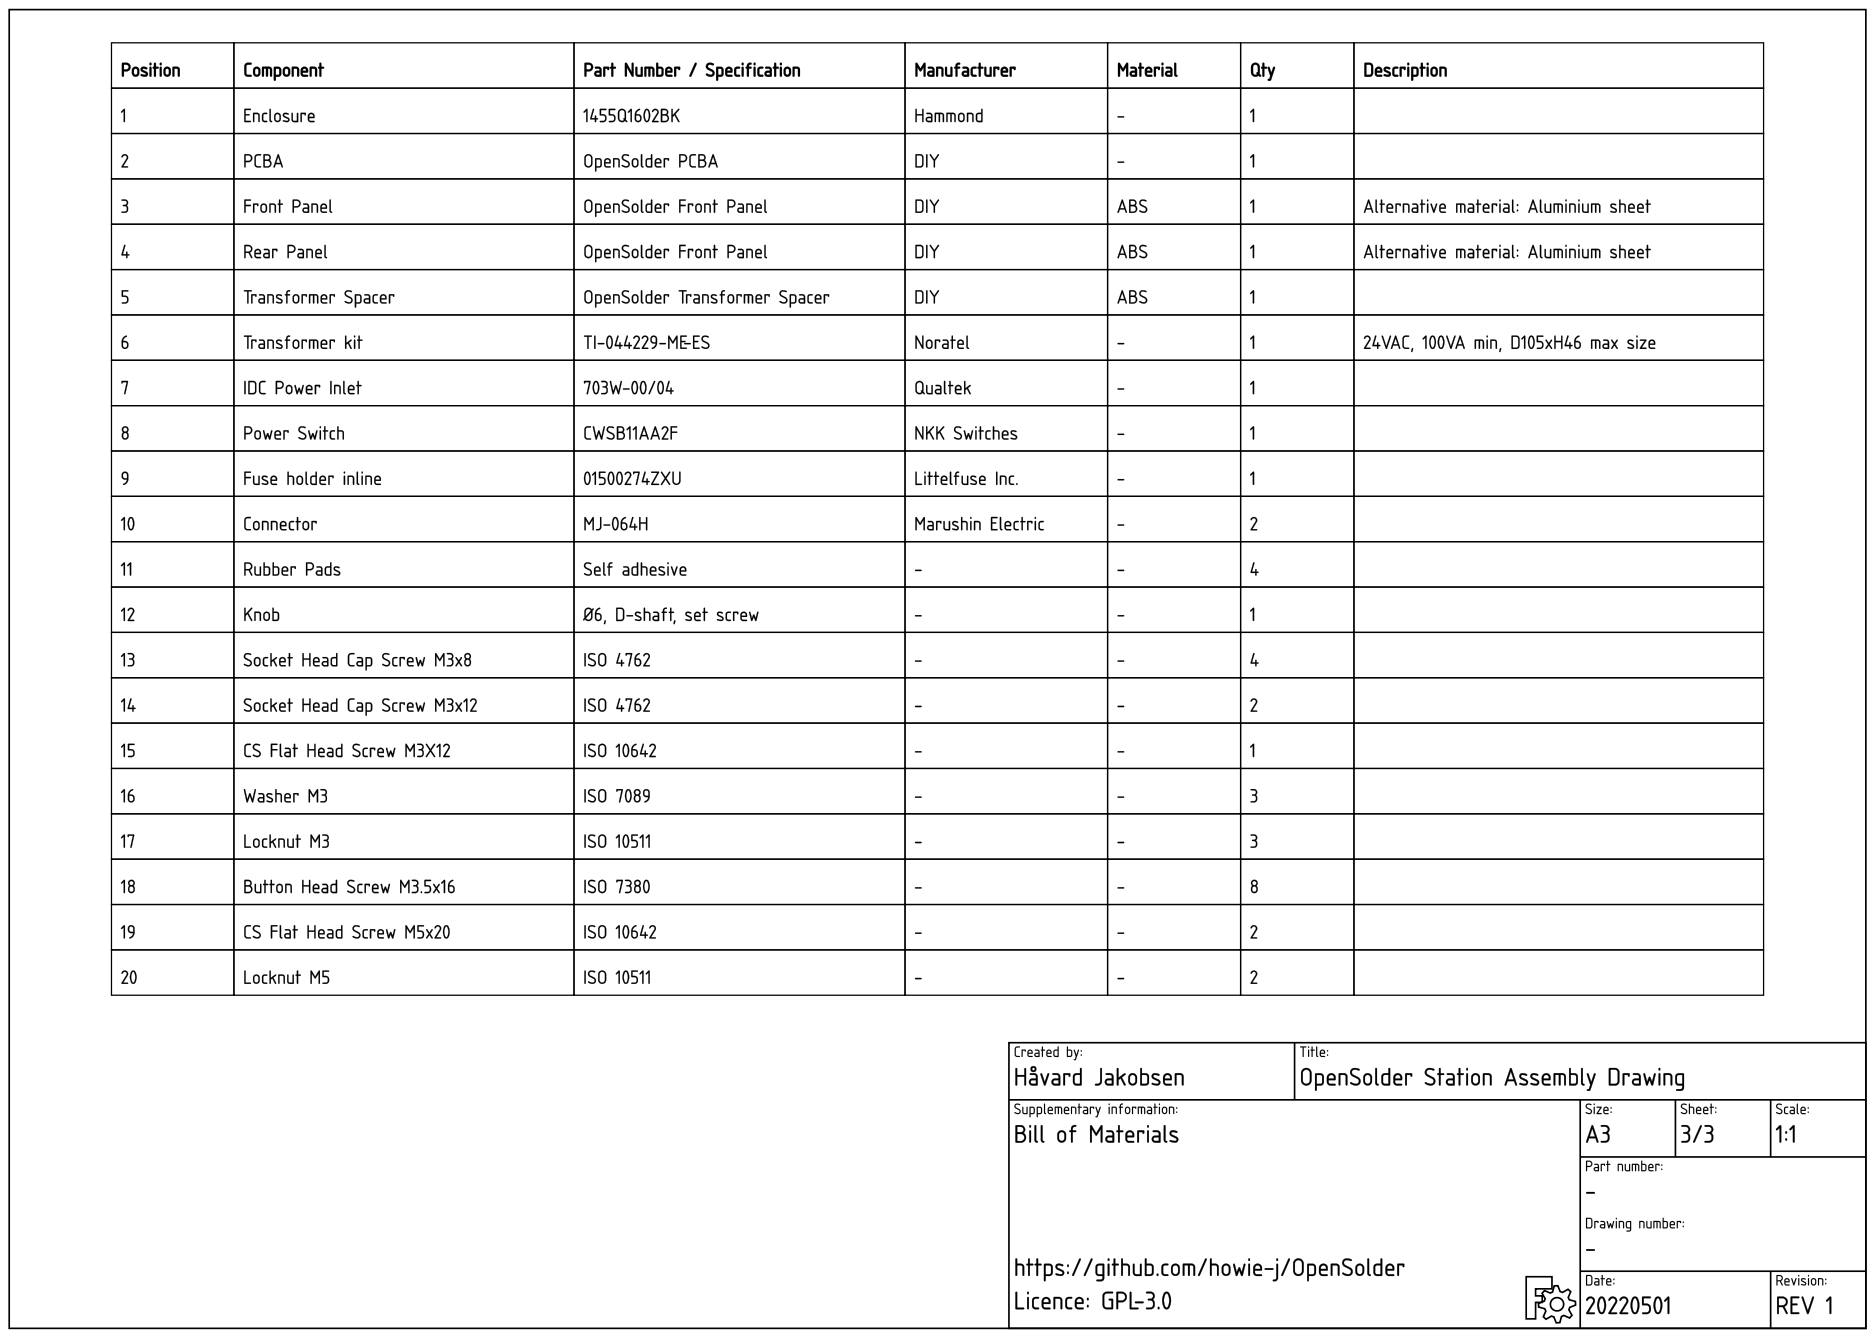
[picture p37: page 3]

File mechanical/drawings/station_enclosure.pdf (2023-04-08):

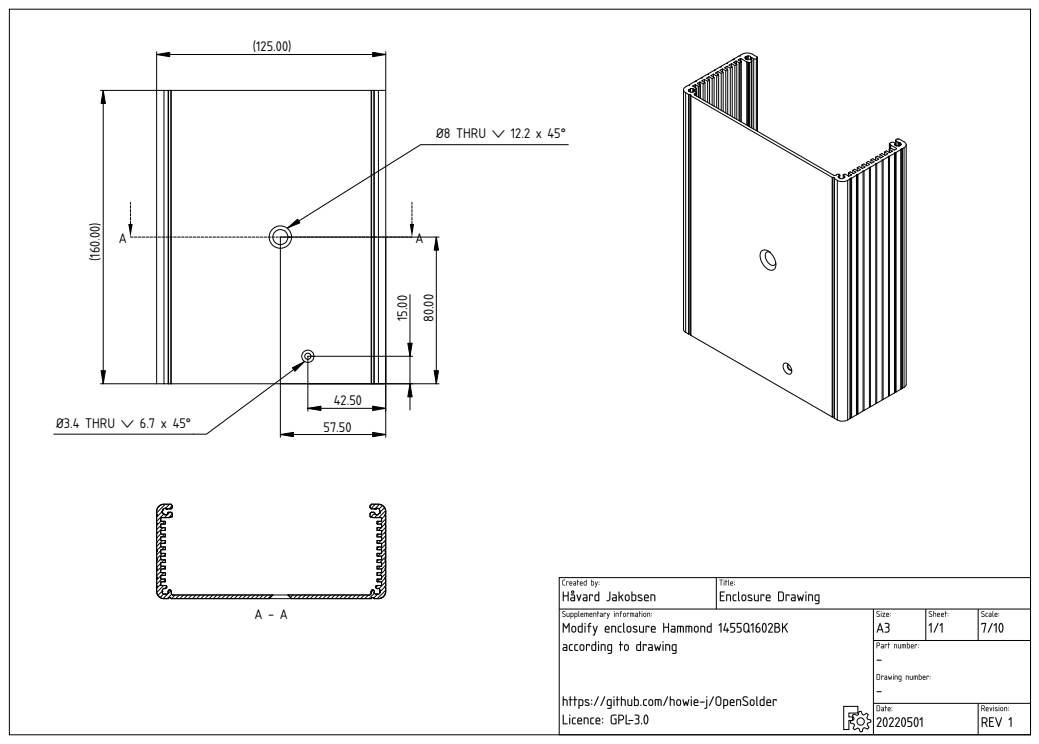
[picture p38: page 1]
Ø8 THRU ⌵ 12.2 x 45°; Ø3.4 THRU ⌵ 6.7 x 45°

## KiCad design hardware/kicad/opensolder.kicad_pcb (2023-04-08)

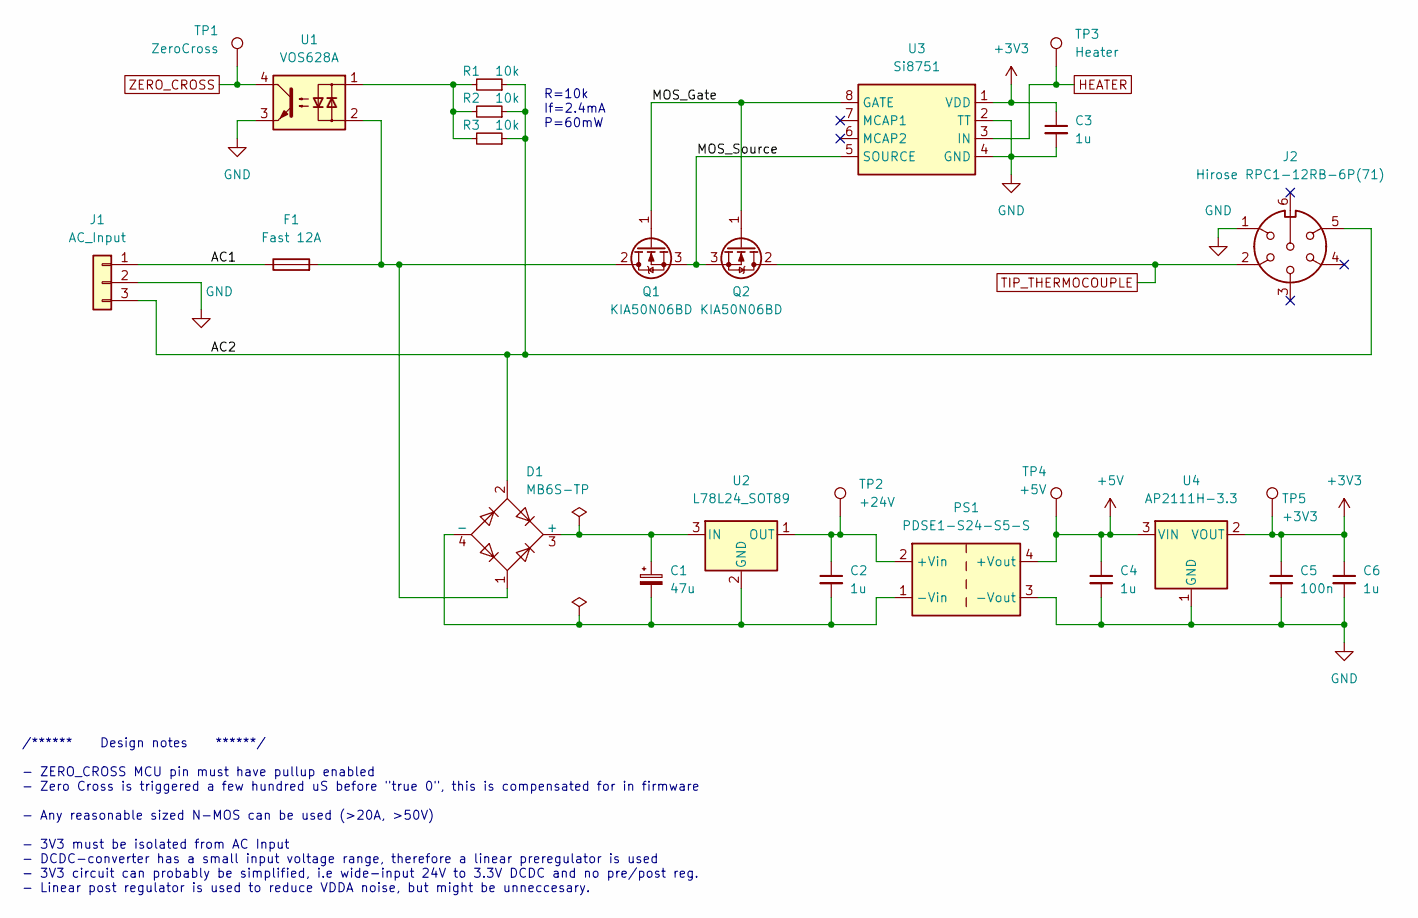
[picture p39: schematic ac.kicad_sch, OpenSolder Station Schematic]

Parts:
C1: 47u; CP_Radial_D8.0mm_P3.50mm
C2, C3, C4, C6: 1u; C_1210_3225Metric
C5: 100n; C_0805_2012Metric
D1: MB6S-TP; TO-269AA
F1: Fast 12A; Fuseholder_Cylinder-5x20mm_Schurter_0031_8201_Horizontal_Op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
J1: AC_Input; PhoenixContact_MSTBVA_2,5_3-G_1x03_P5.00mm_Vertical
J2: Hirose RPC1-12RB-6P(71); Hirose_RPC1
PS1: PDSE1-S24-S5-S; PDSE1_DCDC
Q1, Q2: KIA50N06BD; TO-252-2
R1, R2, R3: 10k; R_0805_2012Metric
TP1: ZeroCross; TestPoint_Pad_D1.0mm
TP2: +24V; TestPoint_Pad_D1.0mm
TP3: Heater; TestPoint_Pad_D1.0mm
TP4: +5V; TestPoint_Pad_D1.0mm
TP5: +3V3; TestPoint_Pad_D1.0mm
U1: VOS628A; SOP-4_4.4x2.6mm_P1.27mm
U2: L78L24_SOT89; SOT-89-3
U3: Si8751; SOIC-8_3.9x4.9mm_P1.27mm
U4: AP2111H-3.3; SOT-223

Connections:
+3V3: C3.1, C5.1, C6.1, TP5.1, U3.1 (VDD), U4.2 (VOUT); also elsewhere on the board
+5V: C4.1, PS1.4 (+Vout), TP4.1, U4.3 (VIN)
/AC/AC1: F1.1, J1.1
/AC/AC2: D1.2, J1.3, J2.5, R1.1, R2.1, R3.1
/AC/MOS_Gate: Q1.1 (G), Q2.1 (G), U3.8 (GATE)
/AC/MOS_Source: Q1.3 (S), Q2.3 (S), U3.5 (SOURCE)
GND: C3.2, C4.2, C5.2, C6.2, J1.2, J2.1, PS1.3 (-Vout), U1.3, U3.2 (TT), U3.4 (GND), U4.1 (GND); also elsewhere on the board
HEATER: TP3.1, U3.3 (IN); also elsewhere on the board
unnamed: C1.1, D1.3 (+), U2.3 (IN)
unnamed: C1.2, C2.2, D1.4 (-), PS1.1 (-Vin), U2.2 (GND)
unnamed: C2.1, PS1.2 (+Vin), TP2.1, U2.1 (OUT)
unnamed: D1.1, F1.2, Q1.2 (D), U1.2
unnamed: R1.2, R2.2, R3.2, U1.1
TIP_THERMOCOUPLE: J2.2, Q2.2 (D); also elsewhere on the board
ZERO_CROSS: TP1.1, U1.4; also elsewhere on the board

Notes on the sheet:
R=10k If=2.4mA P=60mW
/****** Design notes ******/ - ZERO_CROSS MCU pin must have pullup enabled - Zero Cross is triggered a few hundred uS before "true 0", this is compensated for in firmware - Any reasonable sized N-MOS can be used (>20A, >50V) - 3V3 must be isolated from AC Input - DCDC-converter has a small input vo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

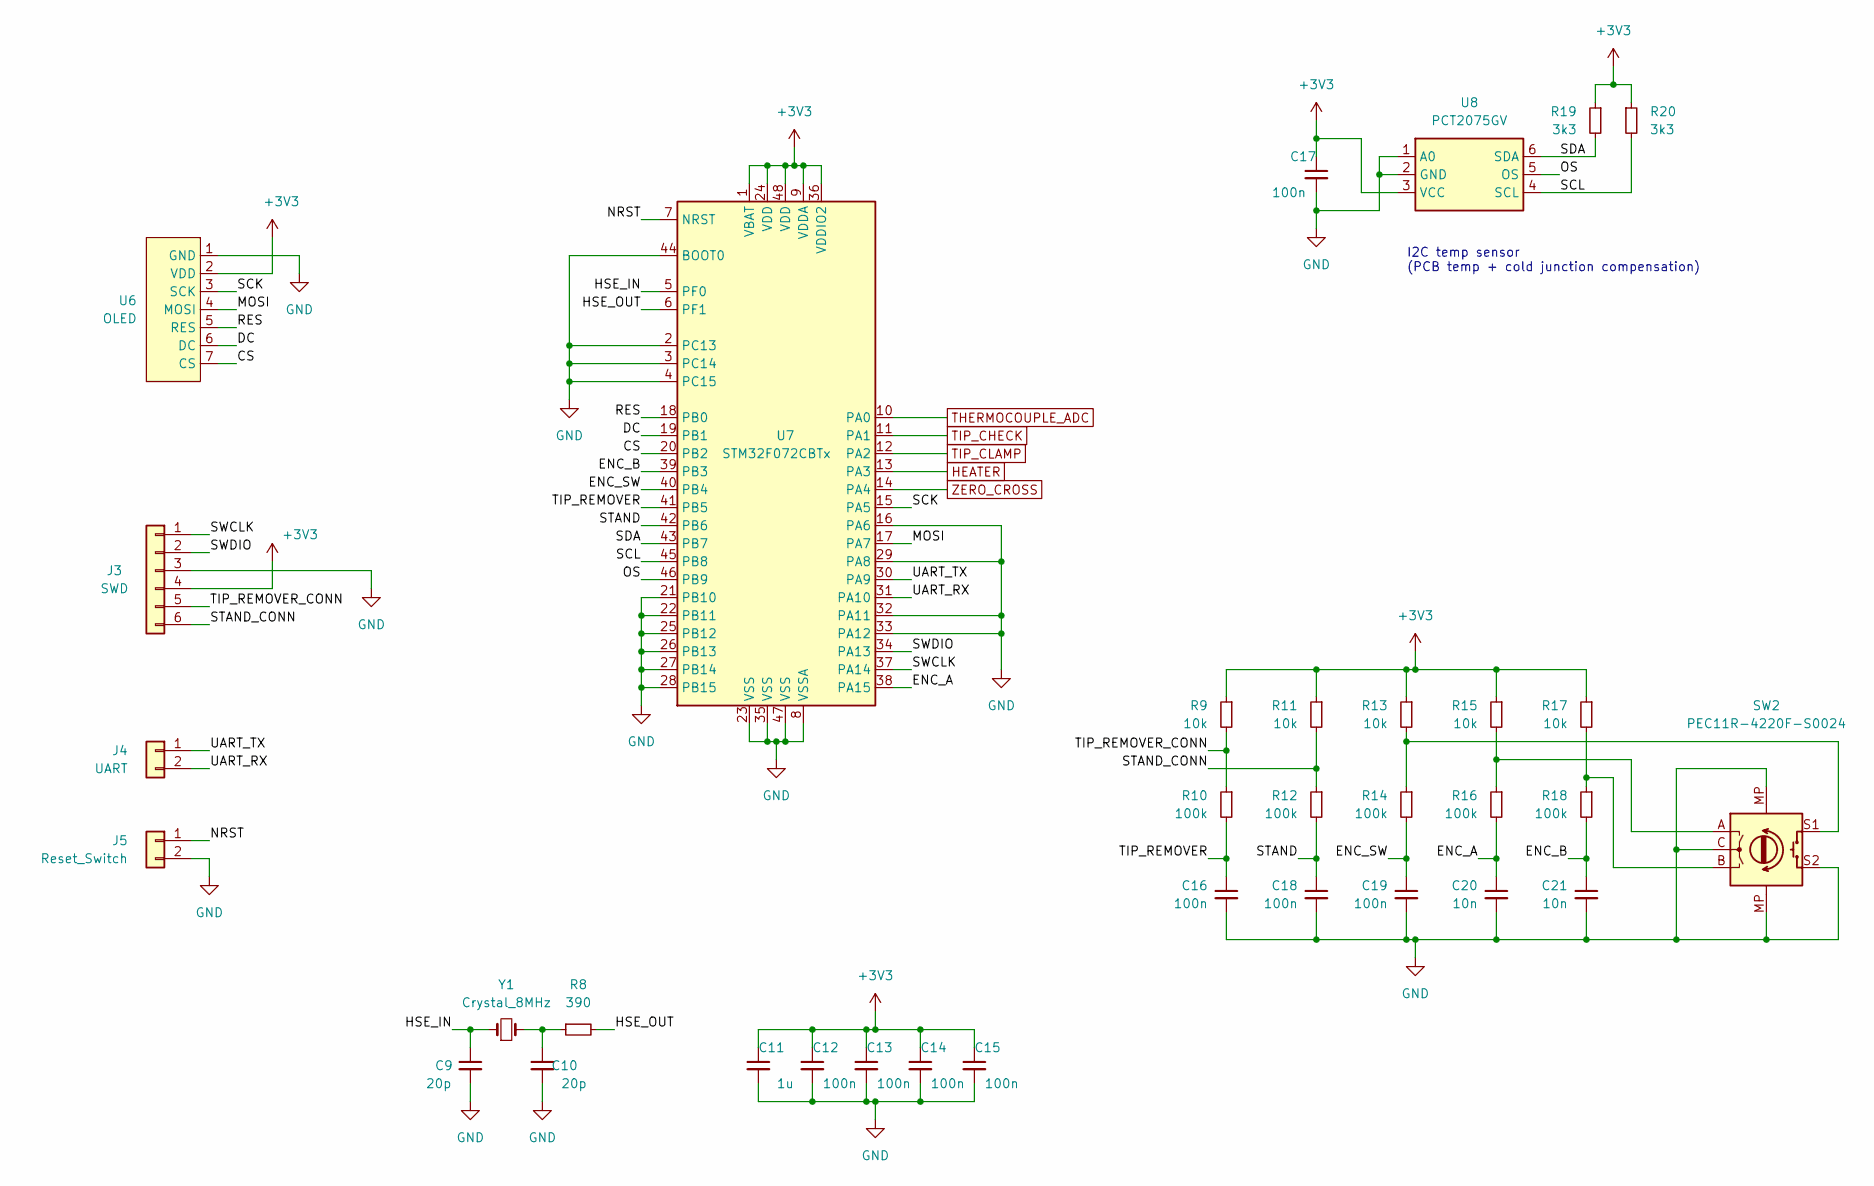
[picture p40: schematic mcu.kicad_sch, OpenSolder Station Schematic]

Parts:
C9, C10: 20p; C_0805_2012Metric
C11: 1u; C_1210_3225Metric
C12, C13, C14, C15, C16, C17, C18, C19: 100n; C_0805_2012Metric
C20, C21: 10n; C_0805_2012Metric
J3: SWD; IDC-Header_2x03_P2.54mm_Vertical
J4: UART; PinSocket_1x02_P2.54mm_Vertical
J5: Reset_Switch; PinSocket_1x02_P2.54mm_Vertical
R8: 390; R_0805_2012Metric
R9, R11, R13, R15, R17: 10k; R_0805_2012Metric
R10, R12, R14, R16, R18: 100k; R_0805_2012Metric
R19, R20: 3k3; R_0805_2012Metric
SW2: PEC11R-4220F-S0024; RotaryEncoder_PEC11R_PEC12R
U6: OLED; OLED_SSD1306_SPI_1.54
U7: STM32F072CBTx; LQFP-48_7x7mm_P0.5mm
U8: PCT2075GV; TSOP-6_1.65x3.05mm_P0.95mm
Y1: Crystal_8MHz; Crystal_SMD_HC49-SD

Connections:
+3V3: C11.1, C12.1, C13.1, C14.1, C15.1, C17.1, J3.4, R9.1, R11.1, R13.1, R15.1, R17.1, R19.1, R20.1, U6.2 (VDD), U7.1 (VBAT), U7.9 (VDDA), U7.24 (VDD), U7.36 (VDDIO2), U7.48 (VDD), U8.3 (VCC); also elsewhere on the board
/MCU/CS: U6.7 (CS), U7.20 (PB2)
/MCU/DC: U6.6 (DC), U7.19 (PB1)
/MCU/ENC_A: C20.1, R16.2, U7.38 (PA15)
/MCU/ENC_B: C21.1, R18.2, U7.39 (PB3)
/MCU/ENC_SW: C19.1, R14.2, U7.40 (PB4)
/MCU/HSE_IN: C9.1, U7.5 (PF0), Y1.1
/MCU/HSE_OUT: R8.2, U7.6 (PF1)
/MCU/MOSI: U6.4 (MOSI), U7.17 (PA7)
/MCU/NRST: J5.1, U7.7 (NRST)
/MCU/OS: U7.46 (PB9), U8.5 (OS)
/MCU/RES: U6.5 (RES), U7.18 (PB0)
/MCU/SCK: U6.3 (SCK), U7.15 (PA5)
/MCU/SCL: R20.2, U7.45 (PB8), U8.4 (SCL)
/MCU/SDA: R19.2, U7.43 (PB7), U8.6 (SDA)
/MCU/STAND: C18.1, R12.2, U7.42 (PB6)
/MCU/STAND_CONN: J3.6, R11.2, R12.1
/MCU/SWCLK: J3.1, U7.37 (PA14)
/MCU/SWDIO: J3.2, U7.34 (PA13)
/MCU/TIP_REMOVER: C16.1, R10.2, U7.41 (PB5)
/MCU/TIP_REMOVER_CONN: J3.5, R9.2, R10.1
/MCU/UART_RX: J4.2, U7.31 (PA10)
/MCU/UART_TX: J4.1, U7.30 (PA9)
GND: C9.2, C10.2, C11.2, C12.2, C13.2, C14.2, C15.2, C16.2, C17.2, C18.2, C19.2, C20.2, C21.2, J3.3, J5.2, SW2.C, SW2.MP, SW2.S2, U6.1 (GND), U7.2 (PC13), U7.3 (PC14), U7.4 (PC15), U7.8 (VSSA), U7.16 (PA6), U7.21 (PB10), U7.22 (PB11), U7.23 (VSS), U7.25 (PB12), U7.26 (PB13), U7.27 (PB14), U7.28 (PB15), U7.29 (PA8), U7.32 (PA11), U7.33 (PA12), U7.35 (VSS), U7.44 (BOOT0), U7.47 (VSS), U8.1 (A0), U8.2 (GND); also elsewhere on the board
HEATER: U7.13 (PA3); also elsewhere on the board
unnamed: C10.1, R8.1, Y1.2
unnamed: R13.2, R14.1, SW2.S1
unnamed: R15.2, R16.1, SW2.A
unnamed: R17.2, R18.1, SW2.B
THERMOCOUPLE_ADC: U7.10 (PA0); also elsewhere on the board
TIP_CHECK: U7.11 (PA1); also elsewhere on the board
TIP_CLAMP: U7.12 (PA2); also elsewhere on the board
ZERO_CROSS: U7.14 (PA4); also elsewhere on the board

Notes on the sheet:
I2C temp sensor (PCB temp + cold junction compensation)

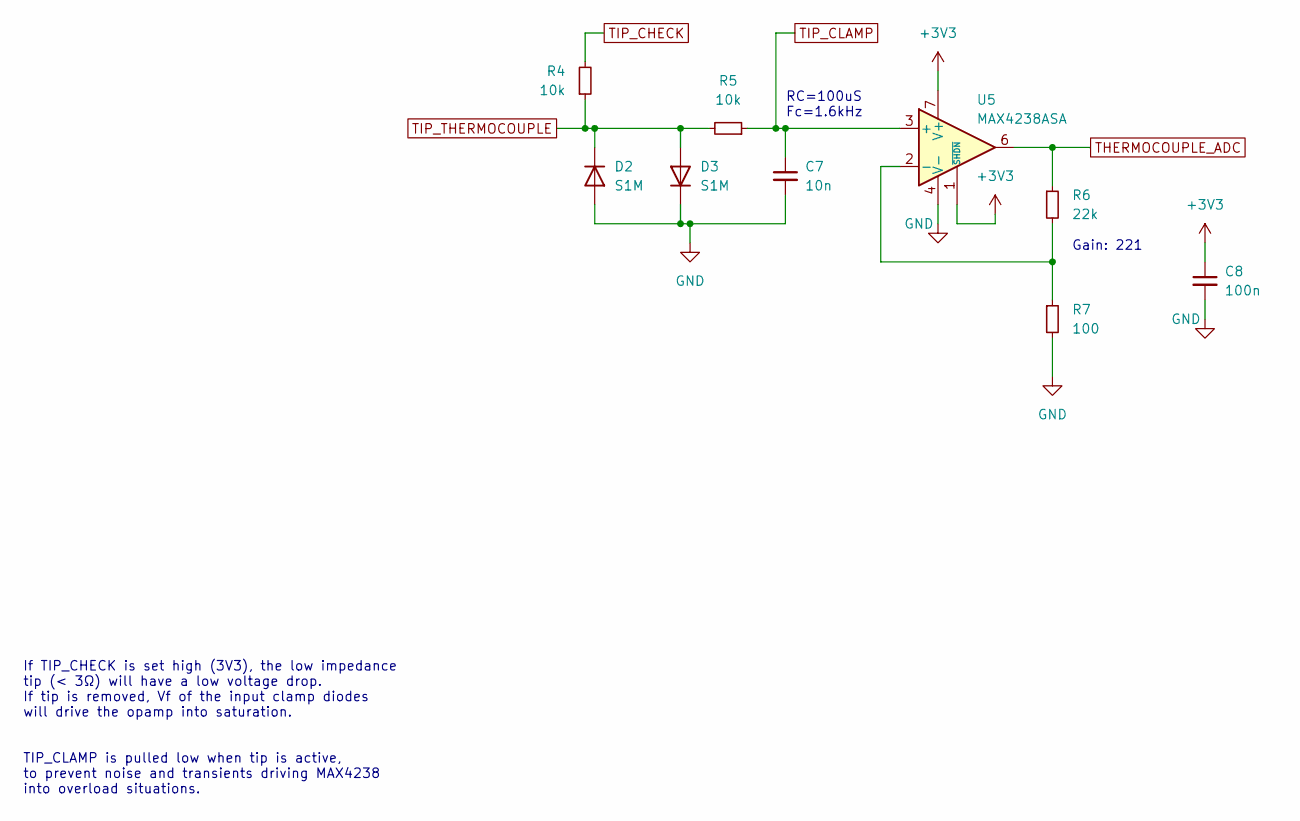
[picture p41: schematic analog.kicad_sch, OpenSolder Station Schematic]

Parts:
C7: 10n; C_0805_2012Metric
C8: 100n; C_0805_2012Metric
D2, D3: S1M; D_SMA
R4, R5: 10k; R_0805_2012Metric
R6: 22k; R_0805_2012Metric
R7: 100; R_0805_2012Metric
U5: MAX4238ASA; SOIC-8_3.9x4.9mm_P1.27mm

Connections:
+3V3: C8.1, U5.1 (~SHDN), U5.7 (V+); also elsewhere on the board
GND: C7.2, C8.2, D2.2 (A), D3.1 (K), R7.2, U5.4 (V-); also elsewhere on the board
unnamed: R6.2, R7.1, U5.2 (-)
THERMOCOUPLE_ADC: R6.1, U5.6; also elsewhere on the board
TIP_CHECK: R4.2; also elsewhere on the board
TIP_CLAMP: C7.1, R5.1, U5.3 (+); also elsewhere on the board
TIP_THERMOCOUPLE: D2.1 (K), D3.2 (A), R4.1, R5.2; also elsewhere on the board

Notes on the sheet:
Gain: 221
RC=100uS Fc=1.6kHz
If TIP_CHECK is set high (3V3), the low impedance tip (< 3Ω) will have a low voltage drop. If tip is removed, Vf of the input clamp diodes will drive the opamp into saturation. TIP_CLAMP is pulled low when tip is active, to prevent noise and transients driving MAX4238 into overload situations.

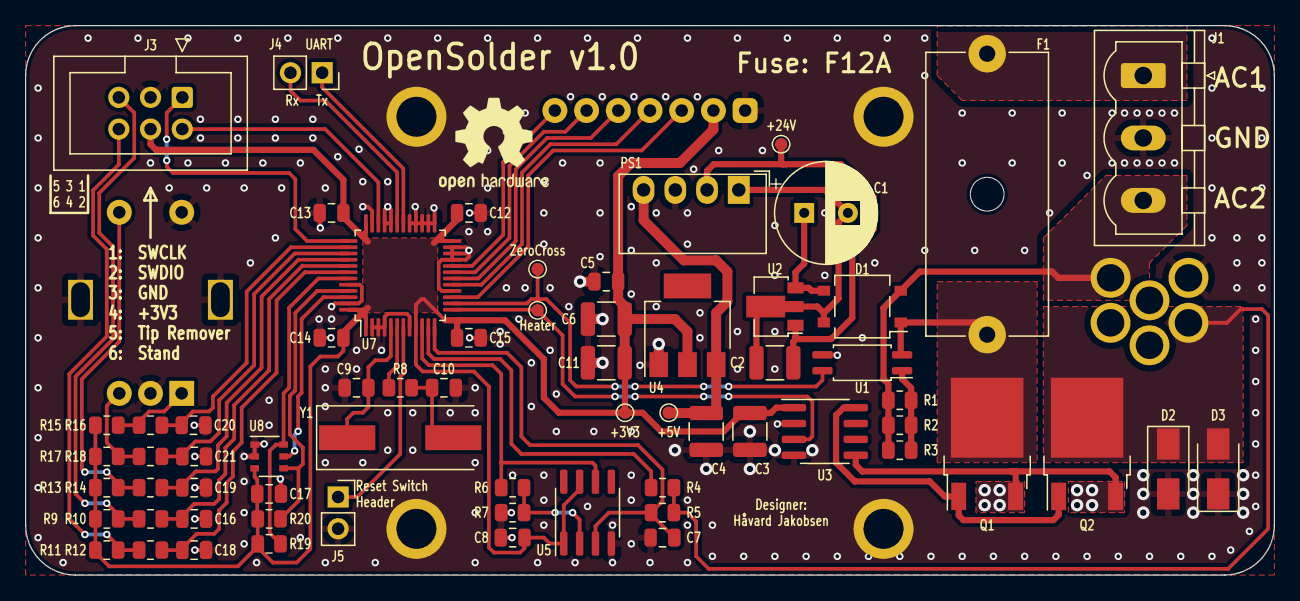
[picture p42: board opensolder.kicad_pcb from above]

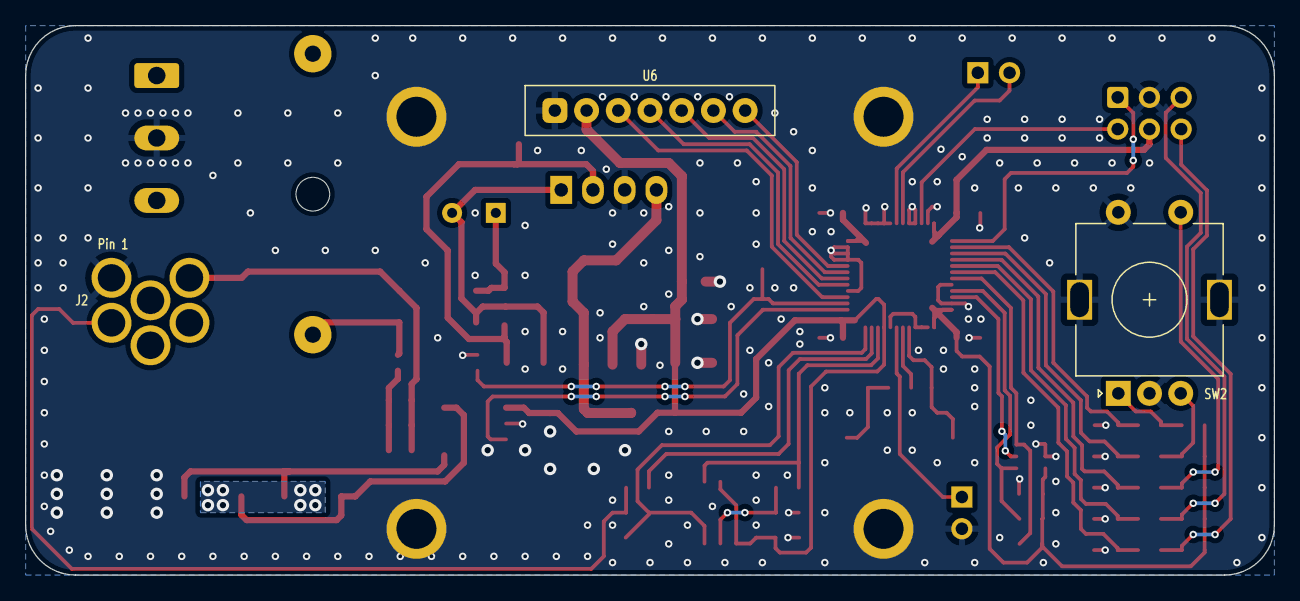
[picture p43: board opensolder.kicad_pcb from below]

Board: 2 copper layers, 100.0 x 44.0 mm, 68 parts (3 on the bottom side), 45 nets.

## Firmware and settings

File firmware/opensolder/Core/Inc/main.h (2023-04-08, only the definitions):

#define THERMOCOUPLE_ADC_Pin GPIO_PIN_0
#define THERMOCOUPLE_ADC_GPIO_Port GPIOA
#define TIP_CHECK_Pin GPIO_PIN_1
#define TIP_CHECK_GPIO_Port GPIOA
#define TIP_CLAMP_Pin GPIO_PIN_2
#define TIP_CLAMP_GPIO_Port GPIOA
#define HEATER_Pin GPIO_PIN_3
#define HEATER_GPIO_Port GPIOA
#define ZERO_CROSS_Pin GPIO_PIN_4
#define ZERO_CROSS_GPIO_Port GPIOA
#define ZERO_CROSS_EXTI_IRQn EXTI4_15_IRQn
#define RES_Pin GPIO_PIN_0
#define RES_GPIO_Port GPIOB
#define DC_Pin GPIO_PIN_1
#define DC_GPIO_Port GPIOB
#define CS_Pin GPIO_PIN_2
#define CS_GPIO_Port GPIOB
#define ENC_A_Pin GPIO_PIN_15
#define ENC_A_GPIO_Port GPIOA
#define ENC_B_Pin GPIO_PIN_3
#define ENC_B_GPIO_Port GPIOB
#define ENC_SW_Pin GPIO_PIN_4
#define ENC_SW_GPIO_Port GPIOB
#define TIP_REMOVER_Pin GPIO_PIN_5
#define TIP_REMOVER_GPIO_Port GPIOB
#define STAND_Pin GPIO_PIN_6
#define STAND_GPIO_Port GPIOB
#define OS_Pin GPIO_PIN_9
#define OS_GPIO_Port GPIOB

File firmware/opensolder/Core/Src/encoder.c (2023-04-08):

/*
 * encoder.c
 *
 * Rotary encoder library for embedded systems
 *
 * License: GPL-3.0 or any later version
 * Copyright (c) 2022 Håvard Jakobsen
 */

#include "encoder.h"

/******    functions    ******/
void encoder_init(encoder *const self, TIM_TypeDef *timer) {
	self->timer = timer;
	self->state = NO_CHANGE;
	self->flag = RESET;
	self->delta = 0;
	self->value = ((self->timer->ARR + 1) / 2);
	self->timer->CNT = self->value;
	self->timer->SR &= ~(1); // Clear SR_UIF (update interrupt flag)
}

uint8_t encoder_event(encoder *const self) {
	uint32_t tmp_CNT = self->timer->CNT;
	if (tmp_CNT != self->value) {
		uint8_t overflow_state = encoder_overflow_check(self);
		if (overflow_state == OVERFLOW) {
			self->state = INCREASE;
		} else if (overflow_state == UNDERFLOW) {
			self->state = DECREASE;
		} else {
			if (tmp_CNT > self->value) {
				self->state = INCREASE;
			} else {
				self->state = DECREASE;
			}
		}
		self->delta = tmp_CNT - self->value;
		self->value = tmp_CNT;
		self->flag = SET;
	} else {
		self->state = NO_CHANGE;
	}
	return self->state;
}

uint32_t get_encoder_value(encoder *const self) {
	return self->value;
}

int32_t get_encoder_delta(encoder *const self) {
	int32_t delta = 0;
	if (self->flag) {
		delta = self->delta;
		self->flag = RESET;
	}
	return delta;
}

uint8_t encoder_overflow_check(encoder *const self) {
	uint8_t overflow_state = 0;
	if (self->timer->SR & 1) {							  // Check if SR_UIF (update interrupt flag) is set
		if (self->timer->CNT <= (self->timer->ARR / 2)) { // Check if counter is under or over the half point of timer ARR
			overflow_state = OVERFLOW;
		} else {
			overflow_state = UNDERFLOW;
		}
		self->timer->SR &= ~(1); // Clear SR_UIF (update interrupt flag)
	}
	return overflow_state;
}

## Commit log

2023-04-08 Initial "Hardware" commit
    [Base Panel.step, Base Panel.stl, Connector IEC-C14 703W-0004.FCStd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]
2023-04-08 Initial "Electronics" commit
    [AC.kicad_sch, Analog.kicad_sch, Component List.csv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]
2023-04-08 Readme preview 4
    [Components.csv]
2023-04-08 firmware + batch file renaming MixedCase to lower_case
    [AC.kicad_sch, Analog.kicad_sch, Components.csv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]
2023-04-08 Fixed tip_change display bug
    [opensolder.c]
2023-04-08 Renamed stm32cubeide -> opensolder to match project name
2023-04-08 Fix constants default value
    [opensolder.h]

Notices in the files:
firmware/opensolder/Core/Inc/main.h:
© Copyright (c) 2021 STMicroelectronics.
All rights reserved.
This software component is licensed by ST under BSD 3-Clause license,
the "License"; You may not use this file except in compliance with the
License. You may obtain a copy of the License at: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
